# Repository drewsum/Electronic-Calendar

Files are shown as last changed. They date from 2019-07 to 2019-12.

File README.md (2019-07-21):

# Electronic-Calendar
Small PCB to show Time, Date, and Day of the Week. Centered around a PIC32MZ

Hardware:
KiCad Project for single PCB is located in hdw/KiCad_Project
Built in KiCad 5.1.0
Requires drewsum's custom libraries for KiCad schematic symbols and PCB footprints, located at: https://github.com/drewsum/KiCad_Custom_Libraries.git

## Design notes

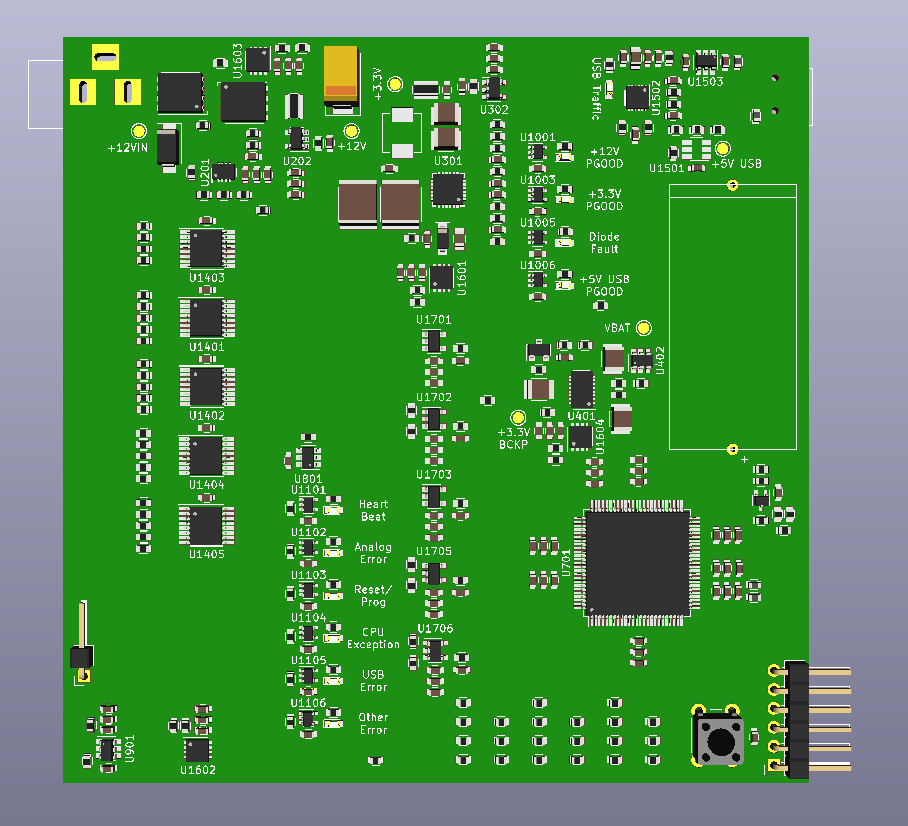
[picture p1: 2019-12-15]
hdw/KiCad_Project/Electronic_Calendar/render_front.PNG

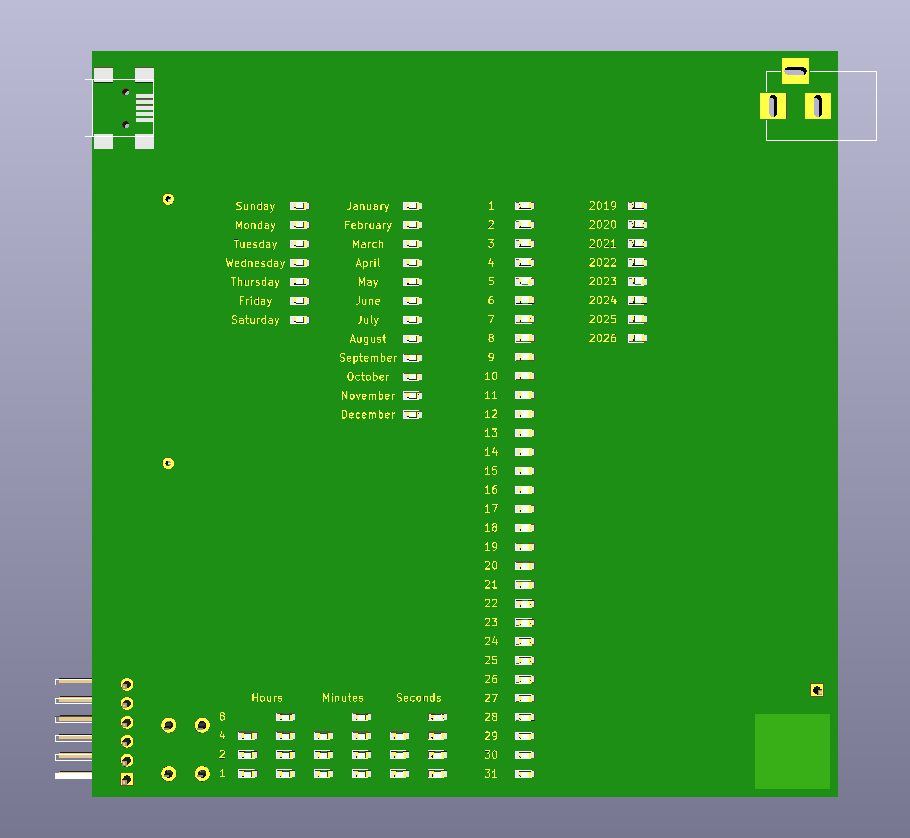
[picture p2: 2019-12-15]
hdw/KiCad_Project/Electronic_Calendar/render_back.PNG

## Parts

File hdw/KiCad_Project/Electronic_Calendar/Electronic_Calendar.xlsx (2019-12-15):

Qty | Reference(s) | Value | Digi-Key PN
1 | BT401 | BR-2/3AE5SPN | P226-ND
51 | C201, C204, C205, C305, C307, C311, C316, C401, C601, C602, C801, C802, C807, C808, C813, C814, C819, C820, C825, C902, C1001, C1003, C1005, C1006, C1101, C1102, C1103, C1104, C1105, C1106, C1401, C1402, C1403, C1404, C1405, C1501, C1502, C1503, C1504, C1506, C1507, C1510, C1601, C1602, C1603, C1610, C1701, C1702, C1709, C1717, C1718 | 0.1uF | 311-1344-1-ND
28 | C202, C206, C304, C313, C803, C804, C809, C810, C815, C816, C821, C822, C901, C903, C1604, C1605, C1606, C1611, C1703, C1704, C1707, C1708, C1711, C1715, C1719, C1720, C1723, C1724 | 10nF | 1276-1921-1-ND
23 | C203, C207, C208, C314, C317, C805, C806, C811, C812, C817, C818, C823, C824, C904, C1607, C1608, C1609, C1612, C1705, C1706, C1713, C1721, C1722 | 1nF | 1276-1018-1-ND
1 | C209 | 100uF | 718-1102-1-ND
2 | C301, C302 | 22uF | 445-1453-1-ND
1 | C306 | 62pF | 1276-2320-1-ND
2 | C308, C310 | 15pF | 478-10289-1-ND
1 | C309 | 2.2uF | 445-5691-1-ND
5 | C312, C315, C402, C403, C404 | 47uF | 490-4844-1-ND
1 | C1505 | 4.7uF | 1276-2972-1-ND
2 | C1508, C1509 | 47pF | 478-1171-1-ND
1 | D201 | 24V | SMAJ24CALFCT-ND
3 | D301, D1601, D1602 | MBR0530 | MBR0530T1GOSCT-ND
4 | D1001, D1003, D1006, D1101 | Green | 160-1446-1-ND
85 | D1005, D1102, D1103, D1104, D1105, D1106, D1201, D1202, D1203, D1204, D1205, D1206, D1207, D1208, D1209, D1210, D1211, D1212, D1213, D1214, D1215, D1216, D1217, D1218, D1219, D1220, D1221, D1222, D1223, D1224, D1225, D1226, D1227, D1228, D1229, D1230, D1231, D1232, D1233, D1234, D1235, D1236, D1237, D1238, D1239, D1240, D1241, D1242, D1243, D1244, D1245, D1246, D1247, D1248, D1249, D1250, D1251, D1252, D1253, D1254, D1255, D1256, D1257, D1258, D1301, D1302, D1303, D1304, D1305, D1306, D1307, D1308, D1309, D1310, D1311, D1312, D1313, D1314, D1315, D1316, D1317, D1318, D1319, D1320, D1321 | Red | 160-1447-1-ND
1 | D1501 | Yellow | 160-1448-1-ND
1 | DOC1501 | COM_Port_Settings
1 | DOC1601 | 0x18
1 | DOC1602 | 0x19
1 | DOC1603 | 0x1A
1 | DOC1604 | 0x1B
1 | J201 | +12V IN | CP-202BH-ND
1 | J601 | PICKIT3 | 2057-PH1RA-06-UA-ND
1 | J1501 | USB_B_Mini | 732-2109-1-ND
1 | L301 | 0.47uH | 541-1231-1-ND
4 | L801, L802, L1501, L1502 | 600R 0.5A | 732-2389-1-ND
2 | Q201, Q202 | IPC100N04S51R2ATMA1 | IPC100N04S51R2ATMA1CT-ND
1 | Q401 | 2N7002
1 | Q601 | BSS214NW | BSS214NWH6327XTSA1CT-ND
1 | R201 | 6.04M | 541-6.04MHCT-ND
1 | R202 | 86.6k | 311-86.6KHRCT-ND
4 | R203, R401, R402, R407 | 243k | 311-243KHRCT-ND
4 | R204, R302, R307, R310 | 100k | A106046CT-ND
4 | R205, R206, R304, R601 | 10 | YAG3351CT-ND
55 | R207, R301, R403, R406, R602, R604, R801, R902, R1101, R1102, R1105, R1106, R1109, R1110, R1401, R1402, R1403, R1404, R1405, R1406, R1407, R1408, R1409, R1410, R1411, R1412, R1413, R1414, R1415, R1416, R1417, R1418, R1419, R1420, R1421, R1422, R1423, R1424, R1501, R1505, R1506, R1507, R1607, R1608, R1609, R1610, R1611, R1612, R1615, R1616, R1701, R1702, R1707, R1709, R1710 | 10k | RMCF0603FT10K0CT-ND
1 | R208 | 5.1k | YAG3621CT-ND
2 | R209, R309 | 0.02 | P16010CT-ND
1 | R210 | 249k | RR08P249KDCT-ND
2 | R303, R308 | 22.1k | P22.1KHCT-ND
1 | R305 | 63.4k | 541-63.4KHCT-ND
1 | R306 | 13.3k | P13.3KHCT-ND
8 | R404, R405, R901, R1703, R1704, R1705, R1711, R1712 | 499 | P499HCT-ND
1 | R603 | 100 | A106047CT-ND
1 | R605 | 0 | PN
37 | R606, R1001, R1003, R1005, R1006, R1103, R1104, R1107, R1108, R1111, R1112, R1201, R1202, R1203, R1204, R1301, R1302, R1303, R1304, R1305, R1306, R1307, R1308, R1309, R1310, R1311, R1312, R1313, R1314, R1315, R1316, R1317, R1318, R1319, R1320, R1321, R1510 | 1k | RMCF0603FT1K00CT-ND
1 | R1502 | 487k | 311-487KHRCT-ND
1 | R1503 | 6.04k | RMCF0603FT6K04CT-ND
1 | R1504 | 40.2k | 311-40.2KHRCT-ND
2 | R1508, R1509 | 27 | RMCF0603FT27R0CT-ND
1 | R1708 | 1.2k | MCT0603-1.20K-CFCT-ND
1 | SW601 | MRST | 450-1650-ND
1 | SW901 | Cap_Touch
1 | U201 | LTC4365DDB | LTC4365IDDB#TRMPBFCT-ND
2 | U202, U302 | INA138 | INA138NACT-ND
1 | U301 | LTC3605A_UF | LTC3605AIUF#TRPBFCT-ND
1 | U401 | LTC4415DHC | LTC4415EDHC#PBF-ND
2 | U402, U801 | TPS22929D | 296-38579-1-ND
1 | U701 | PIC32MZ2048EFG100_IPT | PIC32MZ2048EFG100-I/PT-ND
1 | U901 | AT42QT1010-TSHR | AT42QT1010-TSHRCT-ND
9 | U1001, U1003, U1006, U1101, U1102, U1103, U1104, U1105, U1106 | 74LVC1G06 | 296-8484-1-ND
1 | U1005 | 74LVC1G17 | 296-11934-1-ND
5 | U1401, U1402, U1403, U1404, U1405 | 74HC138 | 296-8228-1-ND
1 | U1501 | LT6700-1-S6 | LT6700CS6-1#TRMPBFCT-ND
1 | U1502 | FT234XD | 768-1178-1-ND
1 | U1503 | TPD3S014DBVR | 296-38835-1-ND
4 | U1601, U1602, U1603, U1604 | MCP9804_DFN | MCP9804T-E/MCCT-ND
5 | U1701, U1702, U1703, U1705, U1706 | OPA340NA | 296-26275-1-ND

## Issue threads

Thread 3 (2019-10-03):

+3.3V Power Supply Stability

drewsum, 2019-10-03:
Compensation is wrong on POS3P3_Power_Supply. Try RITH = 30.1k, CITH = 330pF, CITHP = 22pF, maybe double up on output capacitance. Try to get the switch node to not look like garbage. Also consider lowering switching frequency to 1 MHz from 2.5 MHz

drewsum, 2019-10-04:
Changed Cff to 33pF, no effect

drewsum, 2019-10-04:
Changed Rith to 33k, no effect

drewsum, 2019-10-04:
Changed Cith to 220pF, seems to be less unstable, still not great

drewsum, 2019-10-04:
Changed Cithp to 47pF, no effect

drewsum, 2019-10-04:
Added 200uF ceramic output capacitance, that really seemed to help

drewsum, 2019-10-04:
Added 44uF ceramic capacitance around the board, seemed to help a little more

drewsum, 2019-10-04:
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

Closed 2019-10-25.

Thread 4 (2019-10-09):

Add error handling for USB UART DMA buffer overruns

drewsum, 2019-10-09:
Add more error handling flags for this

drewsum, 2019-11-02:
Flags added, need to write code to implement them

Closed 2019-11-02.

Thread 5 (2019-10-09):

PIC32MZ EF notes for future projects

drewsum, 2019-10-09:
- The RTCC should be configured to use SOSC oscillator instead of INTOSC since INTOSC does not run in sleep mode
- PGC2/PGD2 should be used for programming from PIC KIT 3 since only these programming pins support debugging, not PGC1/PGD1

drewsum, 2019-10-22:
USB UART should have WAKE IN SLEEP disabled/not set on UART initialization since this is what causes the first two lines from PuTTY transmit to be ignored

drewsum, 2019-10-24:
For VDD >= 2.5V, analog input charge pump should be disabled.
Do the following on ADC init function:
`ADCCON1bits.AICPMPEN = 0;
CFGCONbits.IOANCPEN = 0;`

drewsum, 2019-11-11:
SOSC must be fed from an external oscillator, not crystal

drewsum, 2019-11-13:
In the future, I should add a hardware deglitch filter on the capacitive touch signals, since the signal appears to be bouncy

drewsum, 2019-11-14:
Refactor 32MZ interrupt stuff with Macros

drewsum, 2019-11-14:
Only use external oscillators with these MCUs for SOSC and POSC, no crystals allowed per errata

drewsum, 2019-11-16:
Also, don't connect any input signals to any pins that double as JTAG TDO as this pin apparently flutters high and low during ICSP programming. Only use this pin as an output

drewsum, 2019-11-16:
Avoid using the USBID pin (RF3), I believe there's some weird behavior with this pin when USB is disabled. Seeing weird GPIO states with USB disabled

drewsum, 2019-11-16:
> Avoid using the USBID pin (RF3), I believe there's some weird behavior with this pin when USB is disabled. Seeing weird GPIO states with USB disabled

This was confirmed to be an issue on PIC forums and in the datasheet. If VUSB is left unpowered (connected to VSS like I always do) RF3 is not available as a GPIO. Don't use RF3 in the future. This is why the MON_LED stays lit even when disabled

drewsum, 2019-11-19:
Add some kind of bulk decoupling cap to the MCU besides the smaller value decoupling

drewsum, 2019-11-19:
When designing circuits that use the RTCC, don't design an MCU VDD backup circuit like earlier projects.  Use a dedicated RTC IC with backup battery. The MZ is too high power even in sleep, and I ran into a lot of issues getting IDLE mode to work with a backup battery. This sucks but it's not worth the time to get everything working with a backup battery only for the time to be incorrect on wake from sleep and the battery life to be a day long.

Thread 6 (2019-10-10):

Try to convert USB UART receive parser into object based implementation

drewsum, 2019-10-10:
insteadof using an asston of if statements for each serial command, trying switching to using objects with methods and command strings stored within them, and looping through them. That would be awesome

drewsum, 2019-10-22:
Ended up doing this with a hash table, with UTHash.h

Closed 2019-10-22.

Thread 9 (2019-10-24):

Disable Analog Input Charge Pump

drewsum, 2019-10-24:
Pretty sure the analog input charge pump is causing strange ADC conversion results. This bit is enabled by default, and should be disabled in init function

drewsum, 2019-10-24:
For VDD >= 2.5V, analog input charge pump should be disabled.
Do the following on ADC init function:
`ADCCON1bits.AICPMPEN = 0;`
`CFGCONbits.IOANCPEN = 0;`

Closed 2019-10-25.

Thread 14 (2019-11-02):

Add CPU Exceptions error handler flag

drewsum, 2019-11-02:
So that CPU exceptions can be logged across device resets

Closed 2019-11-02.

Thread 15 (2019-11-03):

Fix WDT and DMT timeouts with addition of I2C

drewsum, 2019-11-03:
I've seen some WDT and DMT timeouts after adding the I2C functionality for digital temp sensors. This is probably because of I2C code blocking stuff, and the CPU core getting tied up in the while loops that are built into the I2C code.

* Consider making I2C non-blocking (this would be really hard)
* Also consider clearing the WDT and DMT during I2C blocking while loops

drewsum, 2019-11-05:
This could have something to do with the clear watchdog timer and deadman timer stuff not being all a single instruction operation... I'm calling a function rather than doing inline stuff. Or something to do with system unlock. Think about it

drewsum, 2019-11-06:
It also would appear that the reason this is happening is that sometimes the PIC core randomly stalls. I've seen it where the WDT/DMT may or may not save it/reset it. This should definitely be figured out. May or may not be related to I2C

drewsum, 2019-11-11:
Not related to I2C, it happens on older git commits from long before I2C being integrated. Weird CPU exception issue I think with TLB reads

drewsum, 2019-11-12:
It would appear that this problem was related to common scan ADC cores being assigned differing sampling times/input clock dividers. With all common scan ADCs (except ADC7) set to have the same SAMC and ADCDIV, this problem appears to have disappeared

drewsum, 2019-11-16:
This was both related to the ADC issue described above, and another issue with the heartbeat timer ISR bring called in a loop. Clearing timer 1 every call of the ISR appears to have fixed this

Closed 2019-11-16.

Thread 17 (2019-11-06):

Refactor 32MZ interrupt stuff with Macros

drewsum, 2019-11-06:
Replace the old school switch/case statements with setting bits with macros. This will suck so maybe find a way to script it

drewsum, 2019-11-14:
Not doing this for this project

Closed 2019-11-14.

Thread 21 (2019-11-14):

Figure out MON_LED staying on when device is in reset/idle mode

drewsum, 2019-11-14:
Weird leakage current going on

Closed 2019-11-16.

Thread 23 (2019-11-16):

Add clock switching/slew to pushbutton ISRs for later use in PGOOD failure ISRs

drewsum, 2019-11-16:

drewsum, 2019-11-18:
Did this but without clock slew since it's unclear how to use the SLEWCON register and how it interacts with OSCCON

Closed 2019-11-18.

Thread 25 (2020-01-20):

Figure out random stalls

drewsum, 2020-01-20:
Occasionaly the CPU does not return to main. I'm guessing that an IRQ is not being properly cleared or something. The heartbeat appears to keep beating since there is no WDT timeout when this happens.

drewsum, 2020-01-20:
This may have something to do with the `MCP9804_temp_results` structure not being volatile. I could see the I2C acquisition stuff trying to write while it's being read.

drewsum, 2020-02-23:
> ~~This may have something to do with the `MCP9804_temp_results` structure not being volatile. I could see the I2C acquisition stuff trying to write while it's being read.~~

This is not the case. I'm pretty sure this has something to do with an ADC interrupt not being cleared properly. There are two different sets of ADC interrupt enables, one within the global interrupt controller and another within the ADC module itself. The documentation on how these interact is unclear because mirochip. I'm experimenting with clearing ADC fault interrupt flags. This issue seemed to disappear when I disabled the ADC and reappeared when the ADC was enabled across builds.

drewsum, 2020-02-26:
Unfortunately my bug fix for clearing ADC fault interrupts didn't work, this is still an issue

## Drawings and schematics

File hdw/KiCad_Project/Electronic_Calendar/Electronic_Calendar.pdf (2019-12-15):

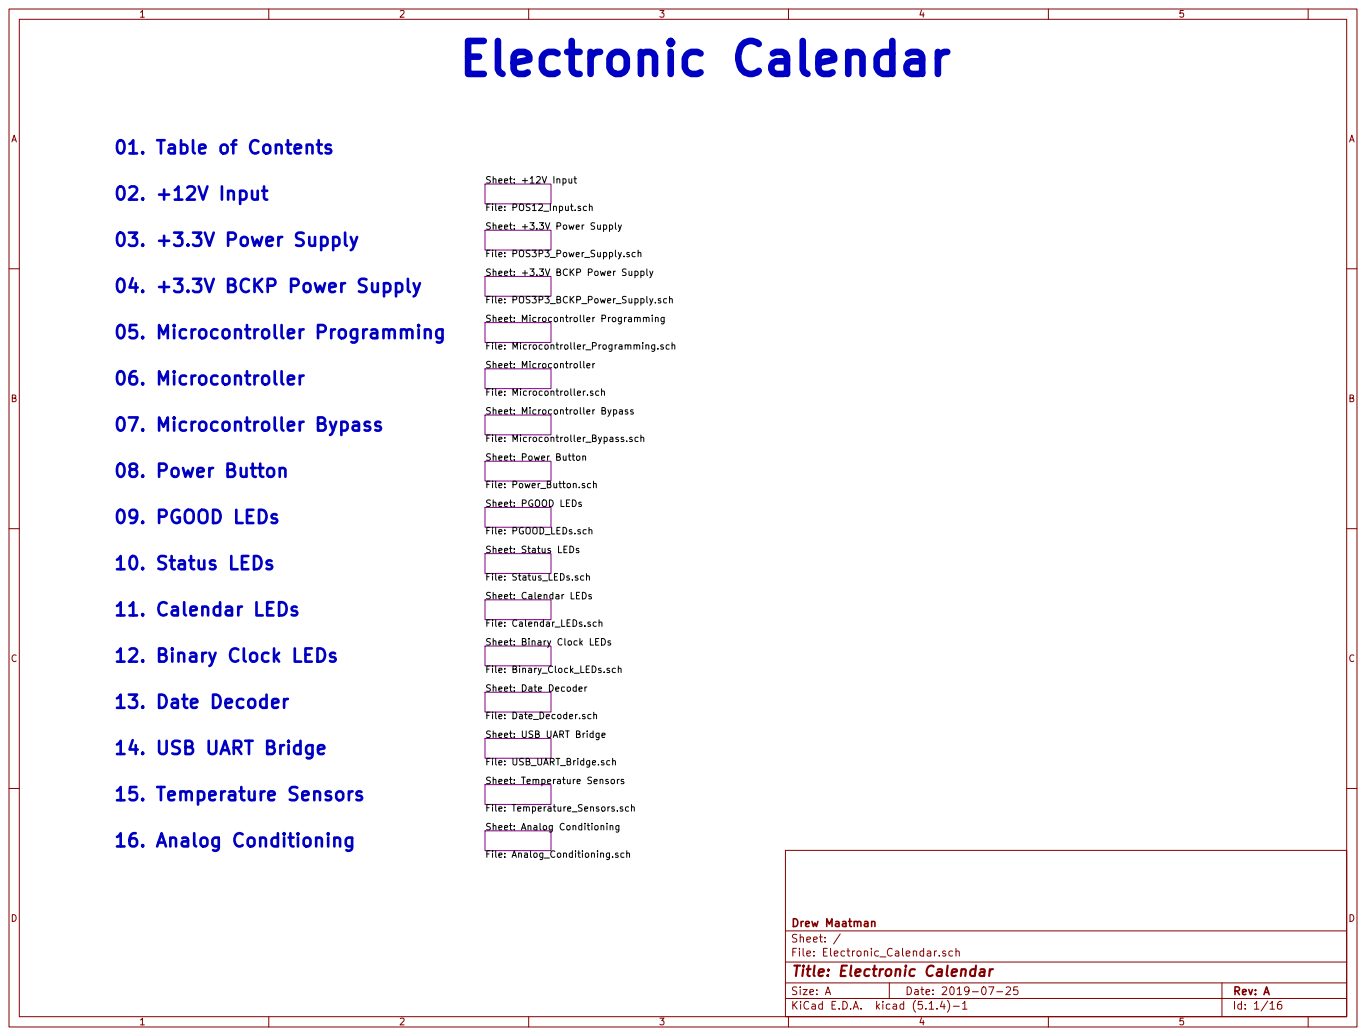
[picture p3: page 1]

Sheet: +12V Input
File: Binary_Clock_LEDs.sch Sheet: Calendar LEDs File: Calendar_LEDs.sch Sheet: Status LEDs File: Status_LEDs.sch Sheet: PGOOD LEDs File: PGOOD_LEDs.sch Sheet: Power Button File: Power_Button.sch Sheet: Microcontroller Bypass

File: POS3P3_Power_Supply.sch
Sheet: +3.3V BCKP Power Supply

File: POS3P3_BCKP_Power_Supply.sch
File: Microcontroller_Bypass.sch Sheet: Microcontroller File: Microcontroller.sch Sheet: Microcontroller Programming

File: USB_UART_Bridge.sch Sheet: Date Decoder File: Date_Decoder.sch Sheet: Binary Clock LEDs

Sheet: USB UART Bridge

File: Electronic_Calendar.sch Sheet: / Drew Maatman

Id: 1/16 Title: Electronic Calendar

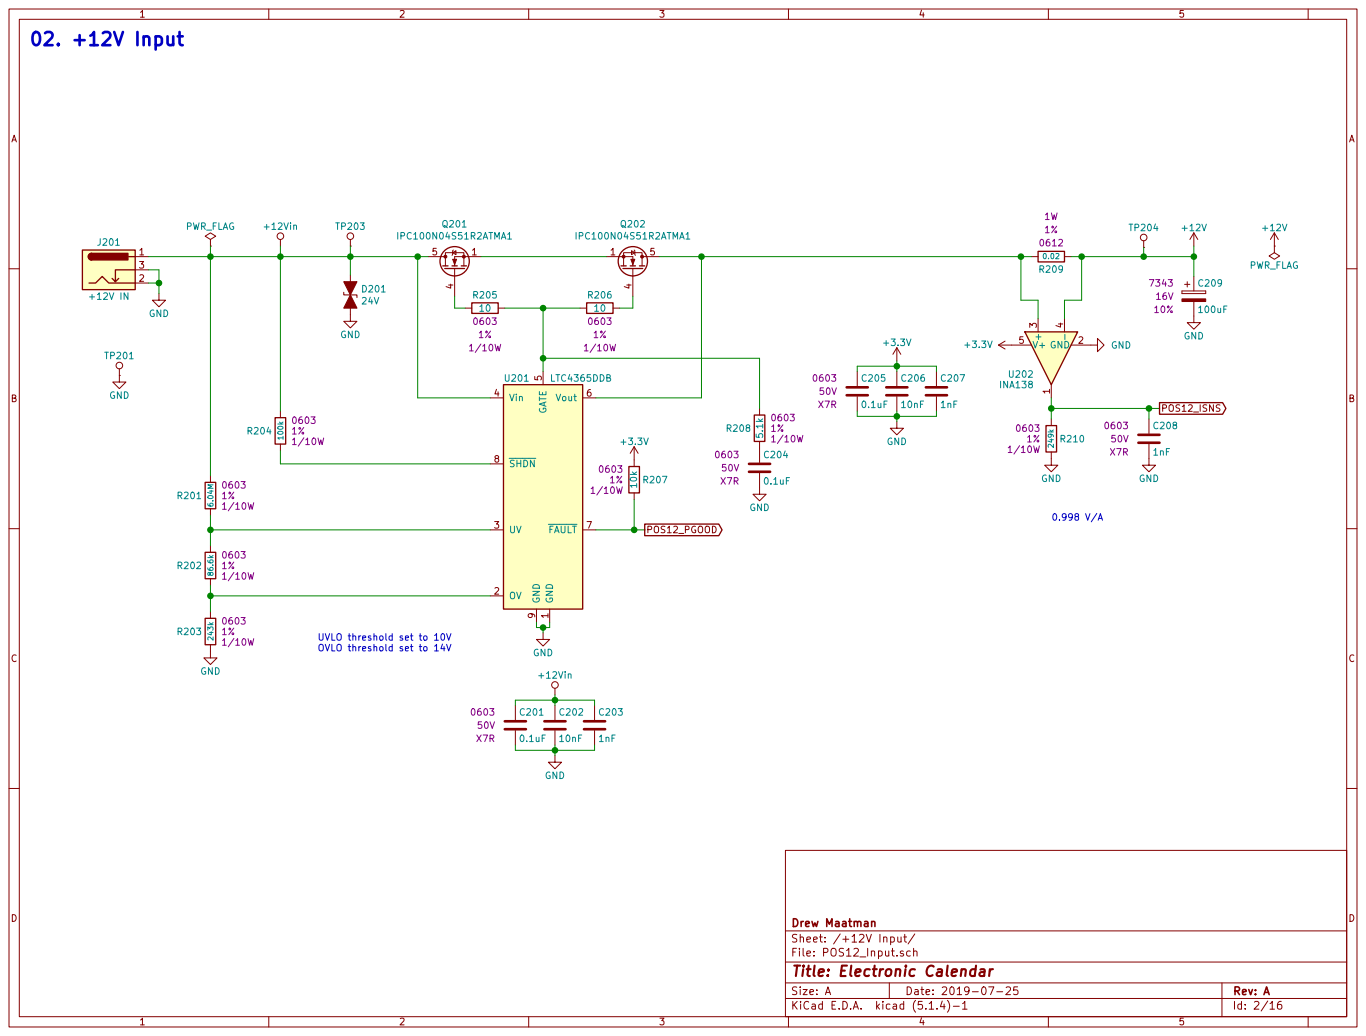
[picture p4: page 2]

POS12_ISNS UVLO threshold set to 10V OVLO threshold set to 14V 02. +12V Input

5 Vout 6 FAULT 7 SHDN 8 GND

1 OV 2 UV 3 Vin 4 GATE

File: POS12_Input.sch
Id: 2/16 Title: Electronic Calendar

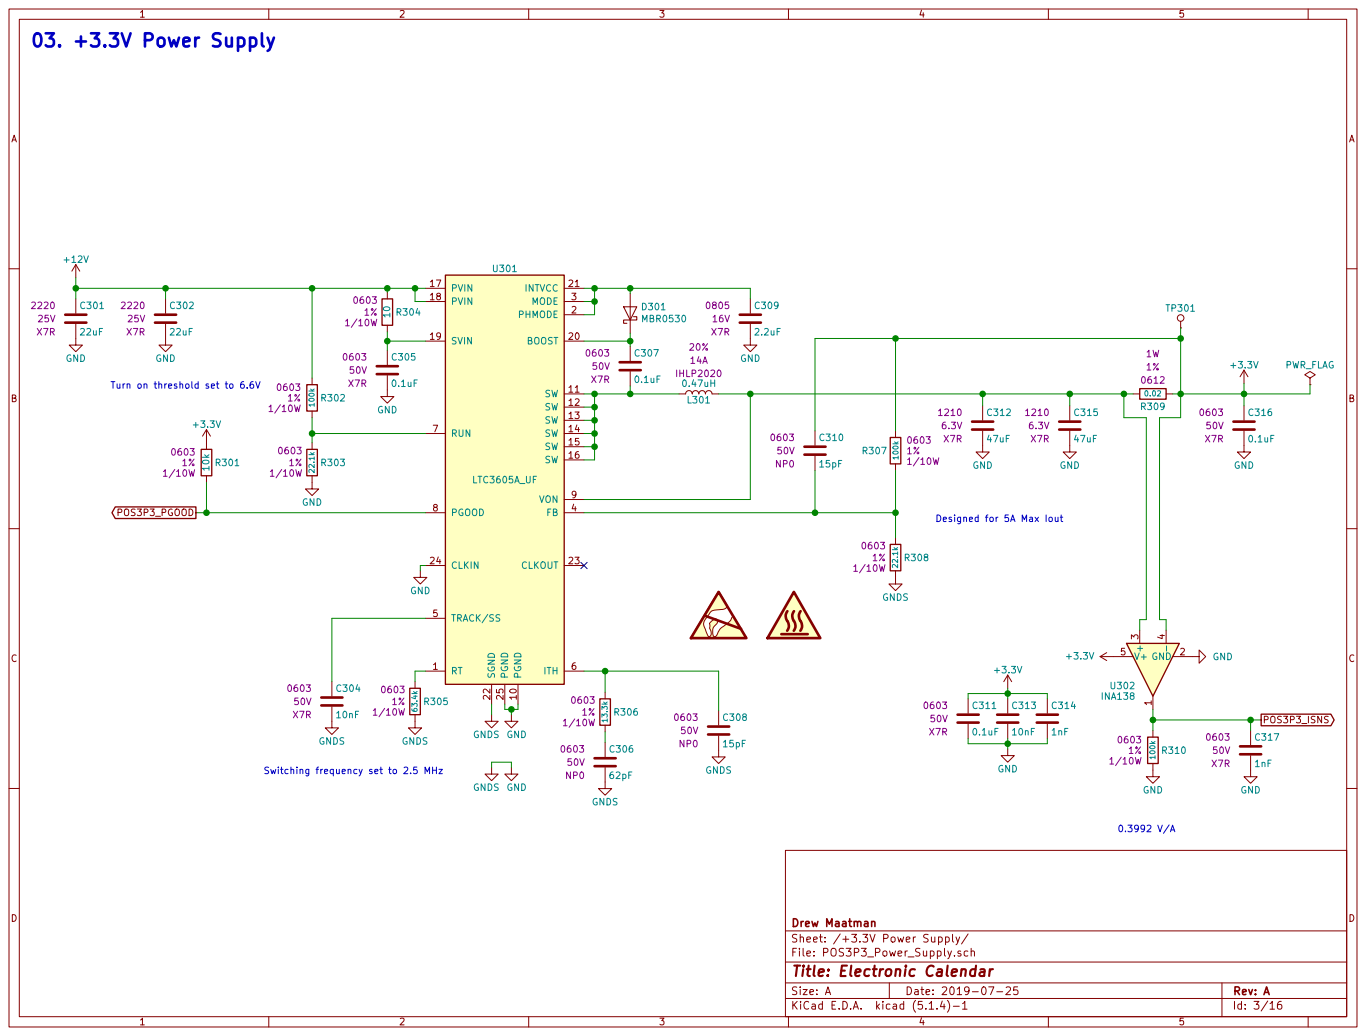
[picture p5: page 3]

Turn on threshold set to 6.6V

Designed for 5A Max Iout

Switching frequency set to 2.5 MHz

File: POS3P3_Power_Supply.sch
Id: 3/16 Title: Electronic Calendar

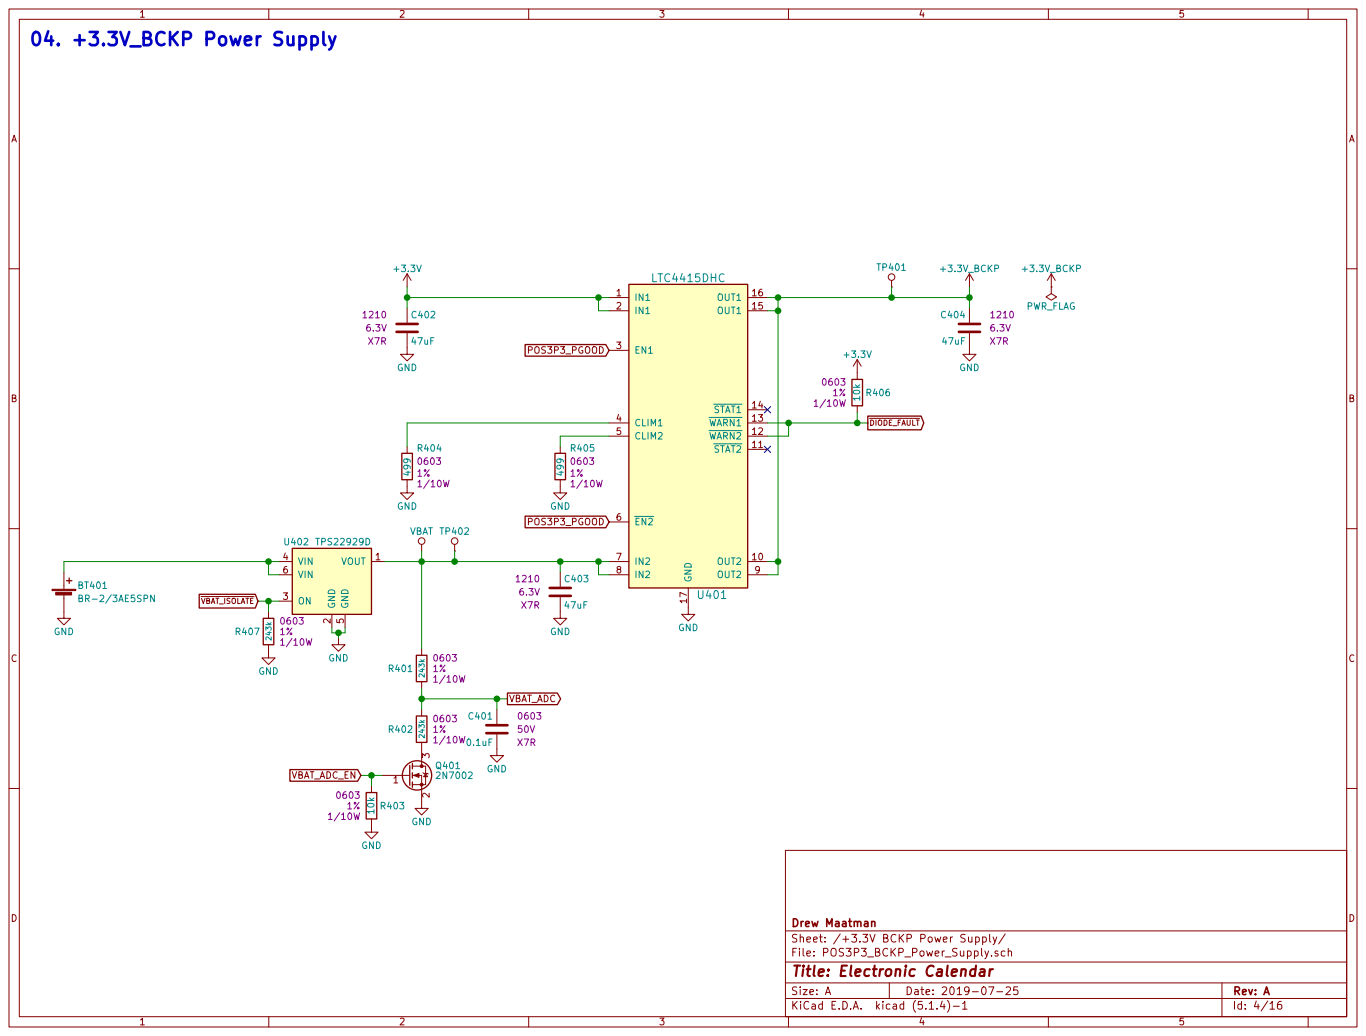
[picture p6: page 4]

Sheet: /+3.3V BCKP Power Supply/ Drew Maatman

File: POS3P3_BCKP_Power_Supply.sch
Id: 4/16 Title: Electronic Calendar

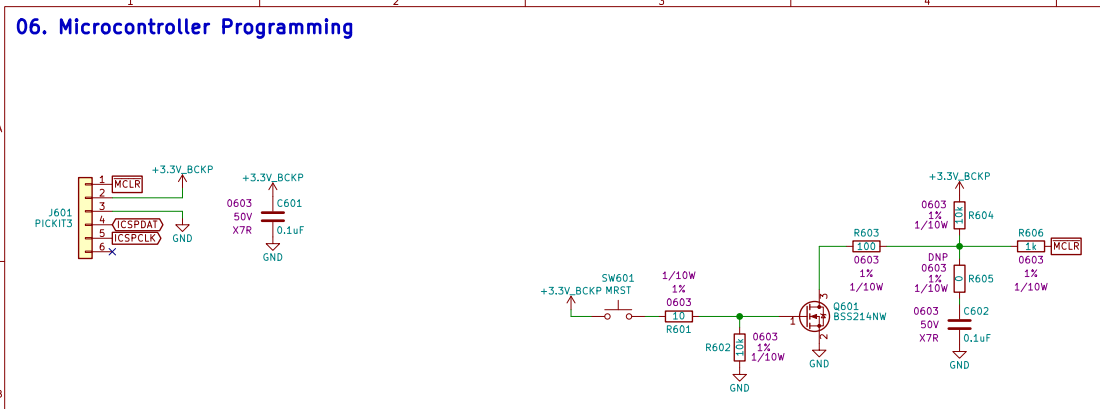
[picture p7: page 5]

ICSPDAT MCLR 06. Microcontroller Programming

Sheet: /Microcontroller Programming/ Drew Maatman

File: Microcontroller_Programming.sch
Id: 5/16 Title: Electronic Calendar

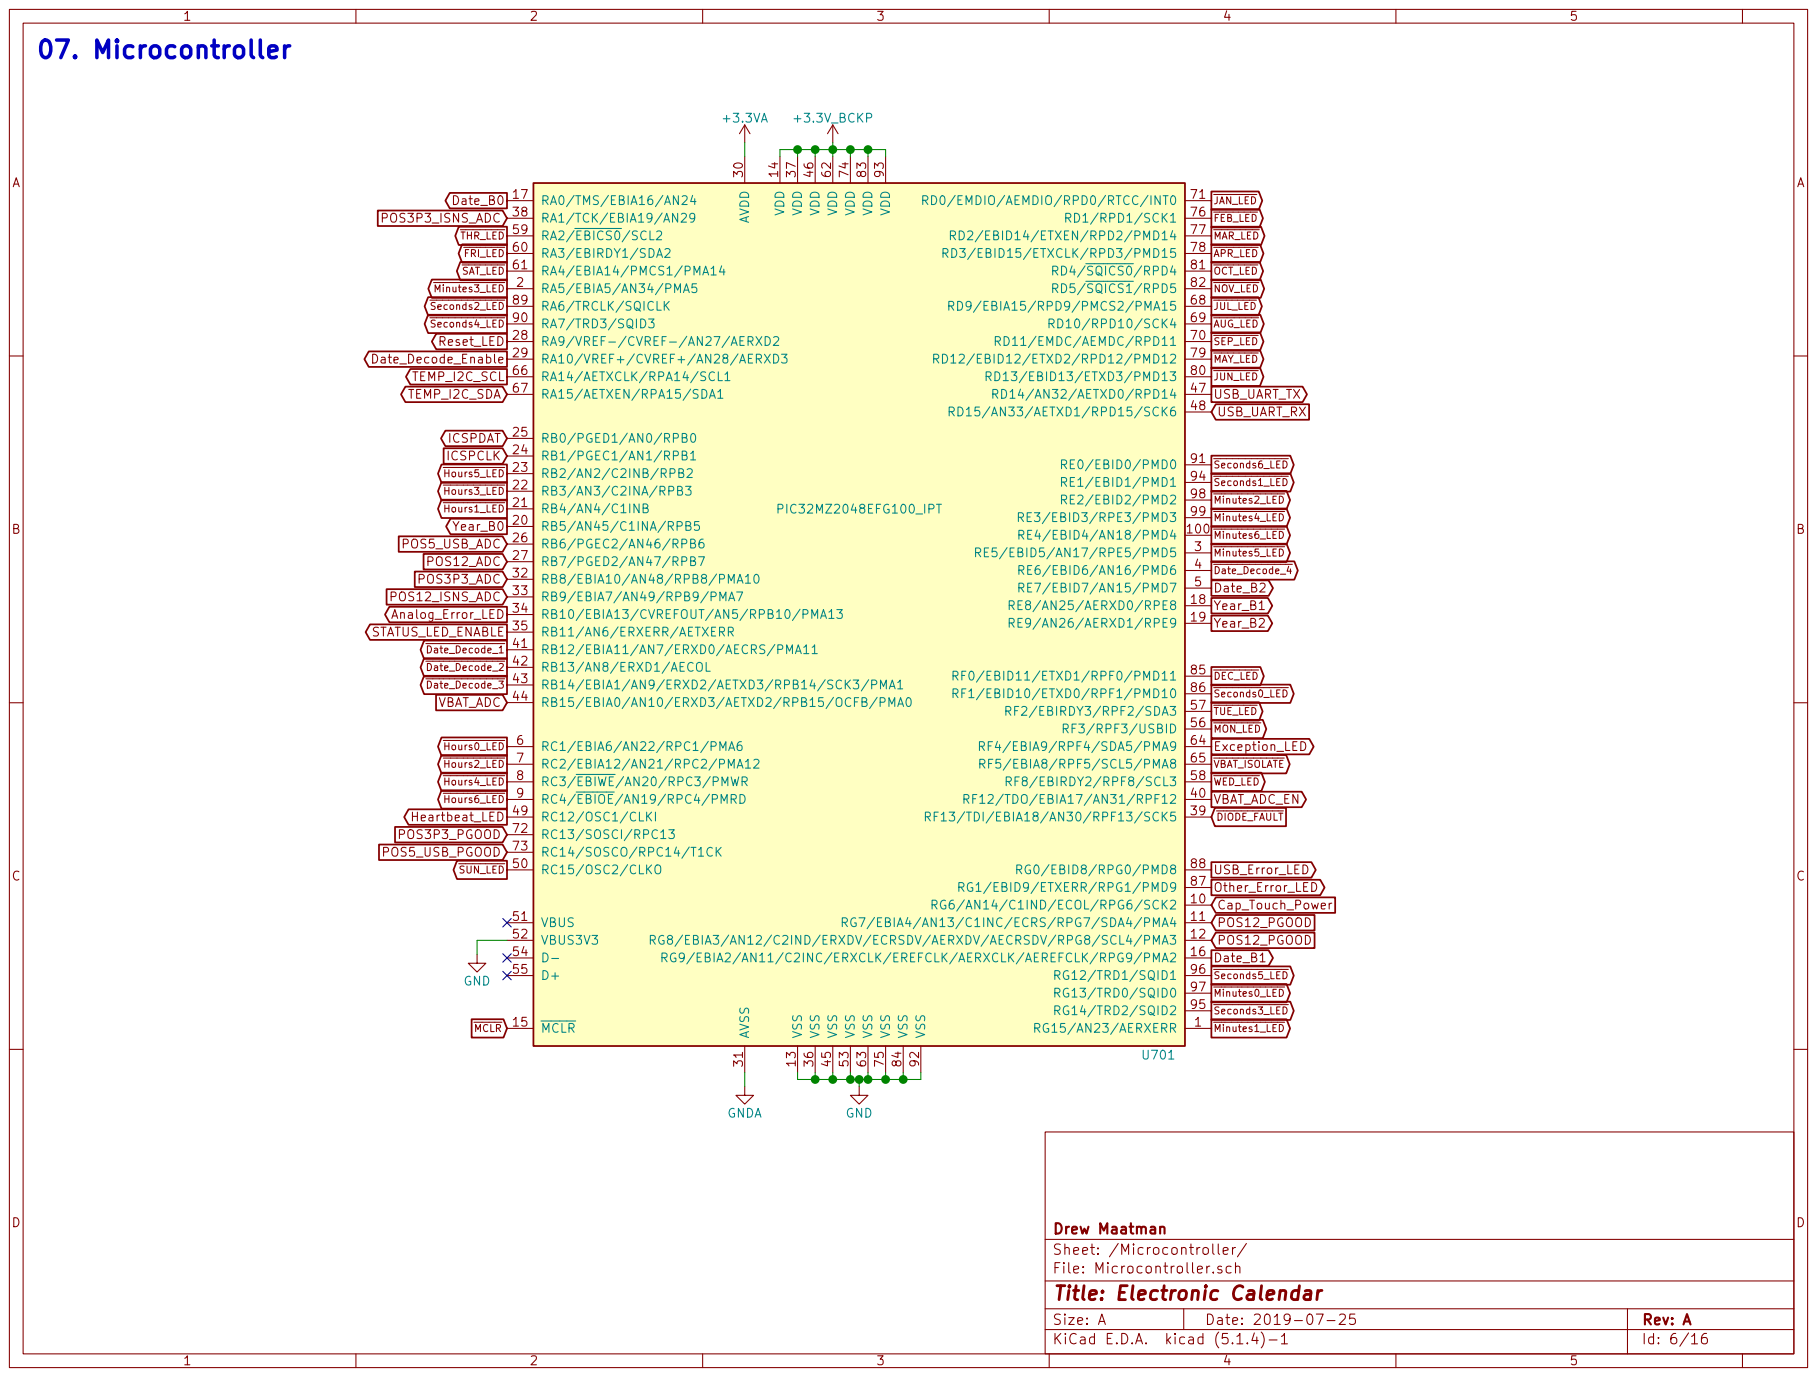
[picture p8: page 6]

Id: 6/16 Title: Electronic Calendar File: Microcontroller.sch Sheet: /Microcontroller/ Drew Maatman

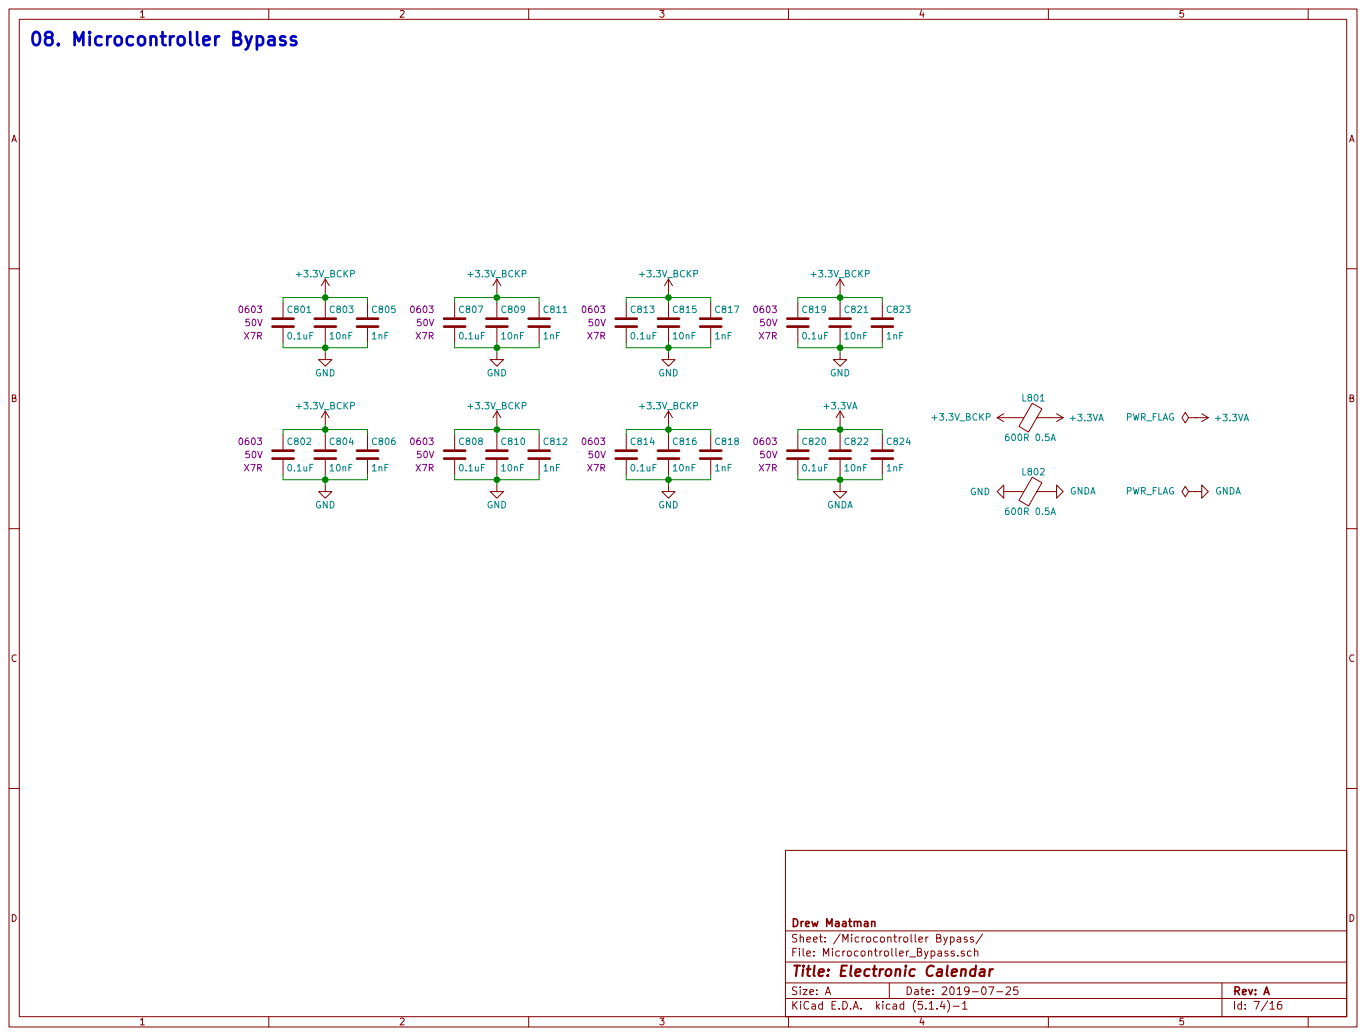
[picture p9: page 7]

Sheet: /Microcontroller Bypass/ Drew Maatman

File: Microcontroller_Bypass.sch
Id: 7/16 Title: Electronic Calendar

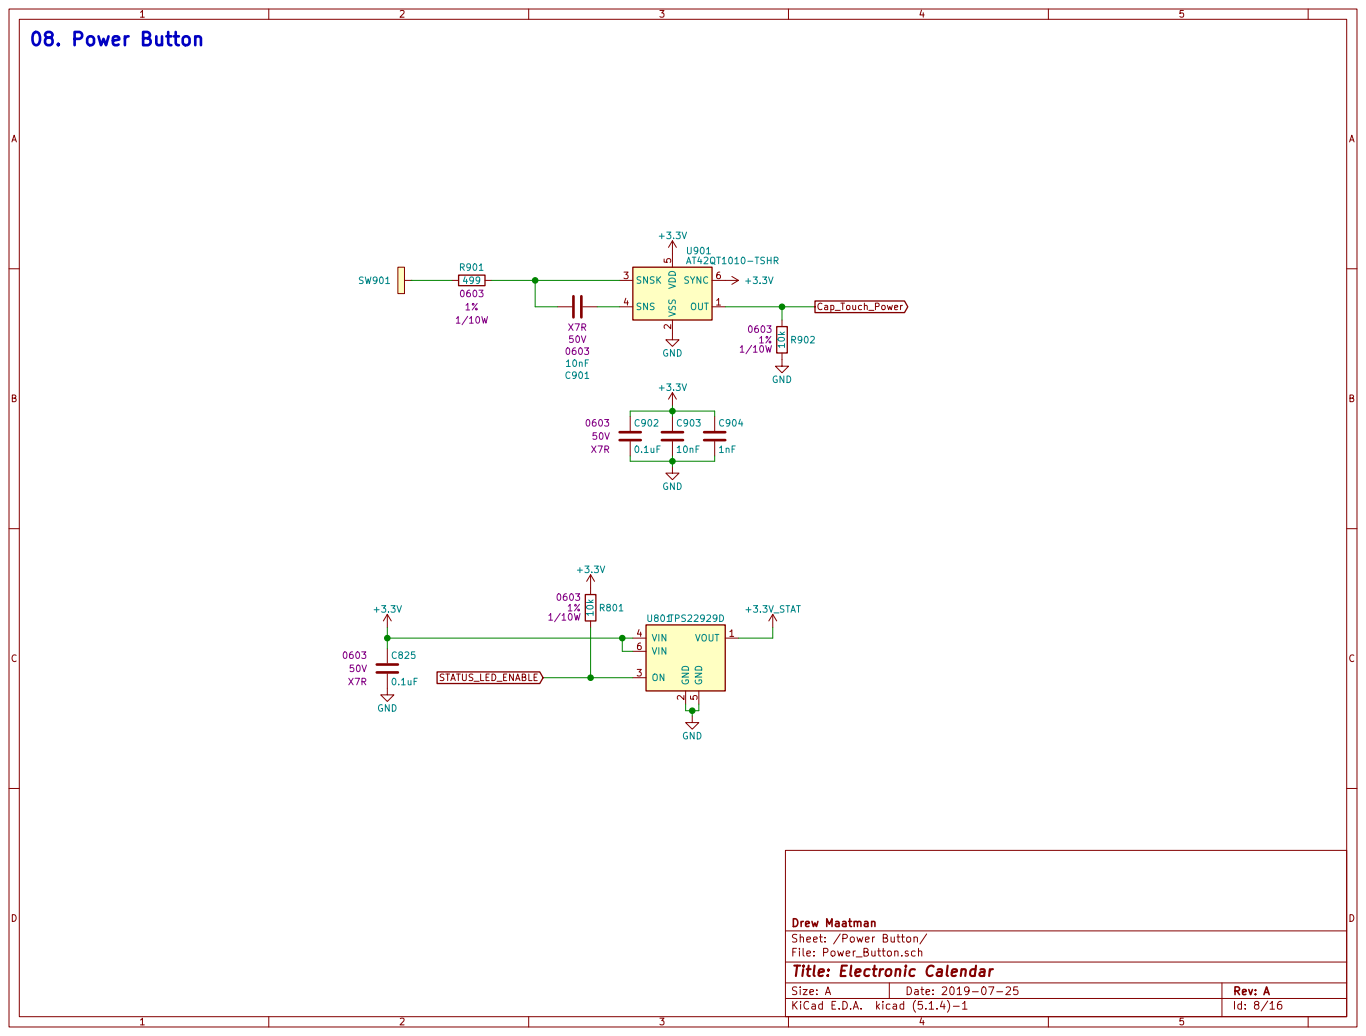
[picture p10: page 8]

File: Power_Button.sch Sheet: /Power Button/ Drew Maatman

Id: 8/16 Title: Electronic Calendar

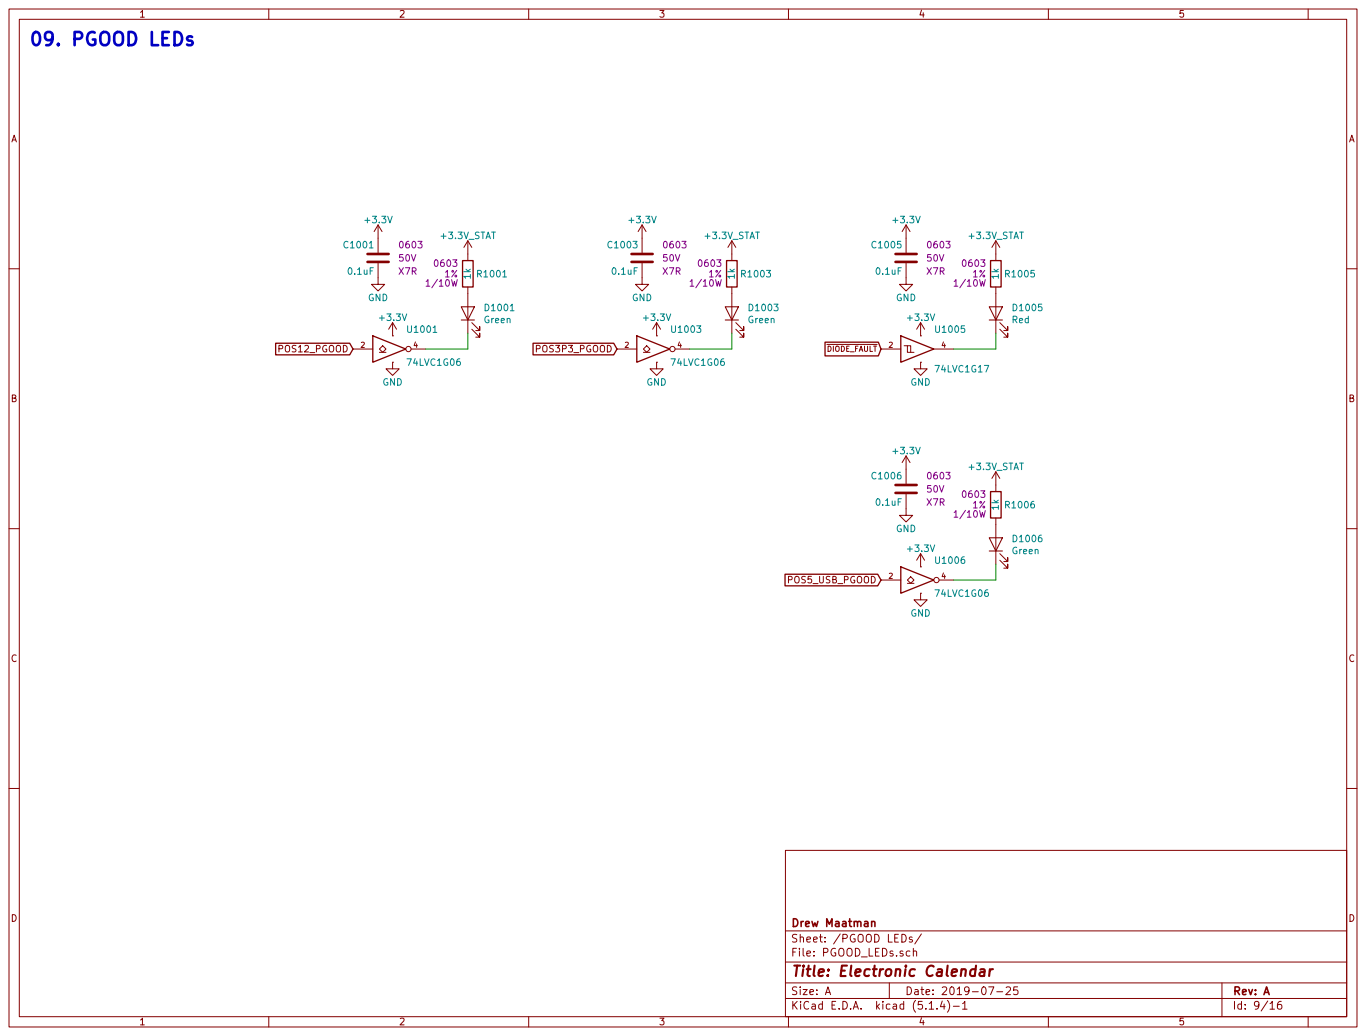
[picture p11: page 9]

File: PGOOD_LEDs.sch Sheet: /PGOOD LEDs/ Drew Maatman

Id: 9/16 Title: Electronic Calendar

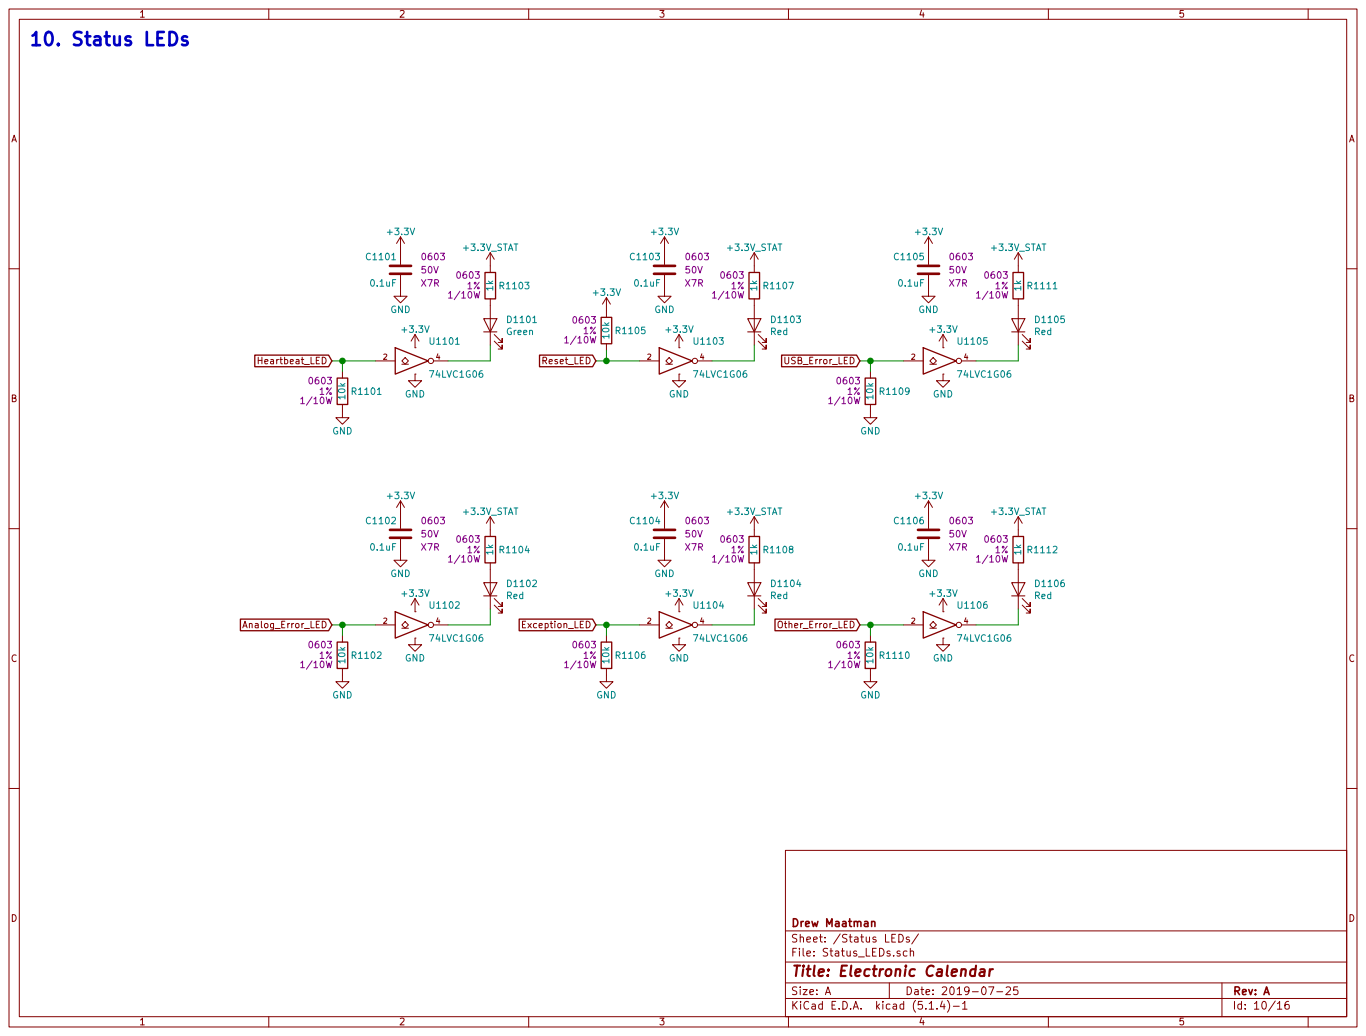
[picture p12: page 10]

File: Status_LEDs.sch Sheet: /Status LEDs/ Drew Maatman

Id: 10/16 Title: Electronic Calendar

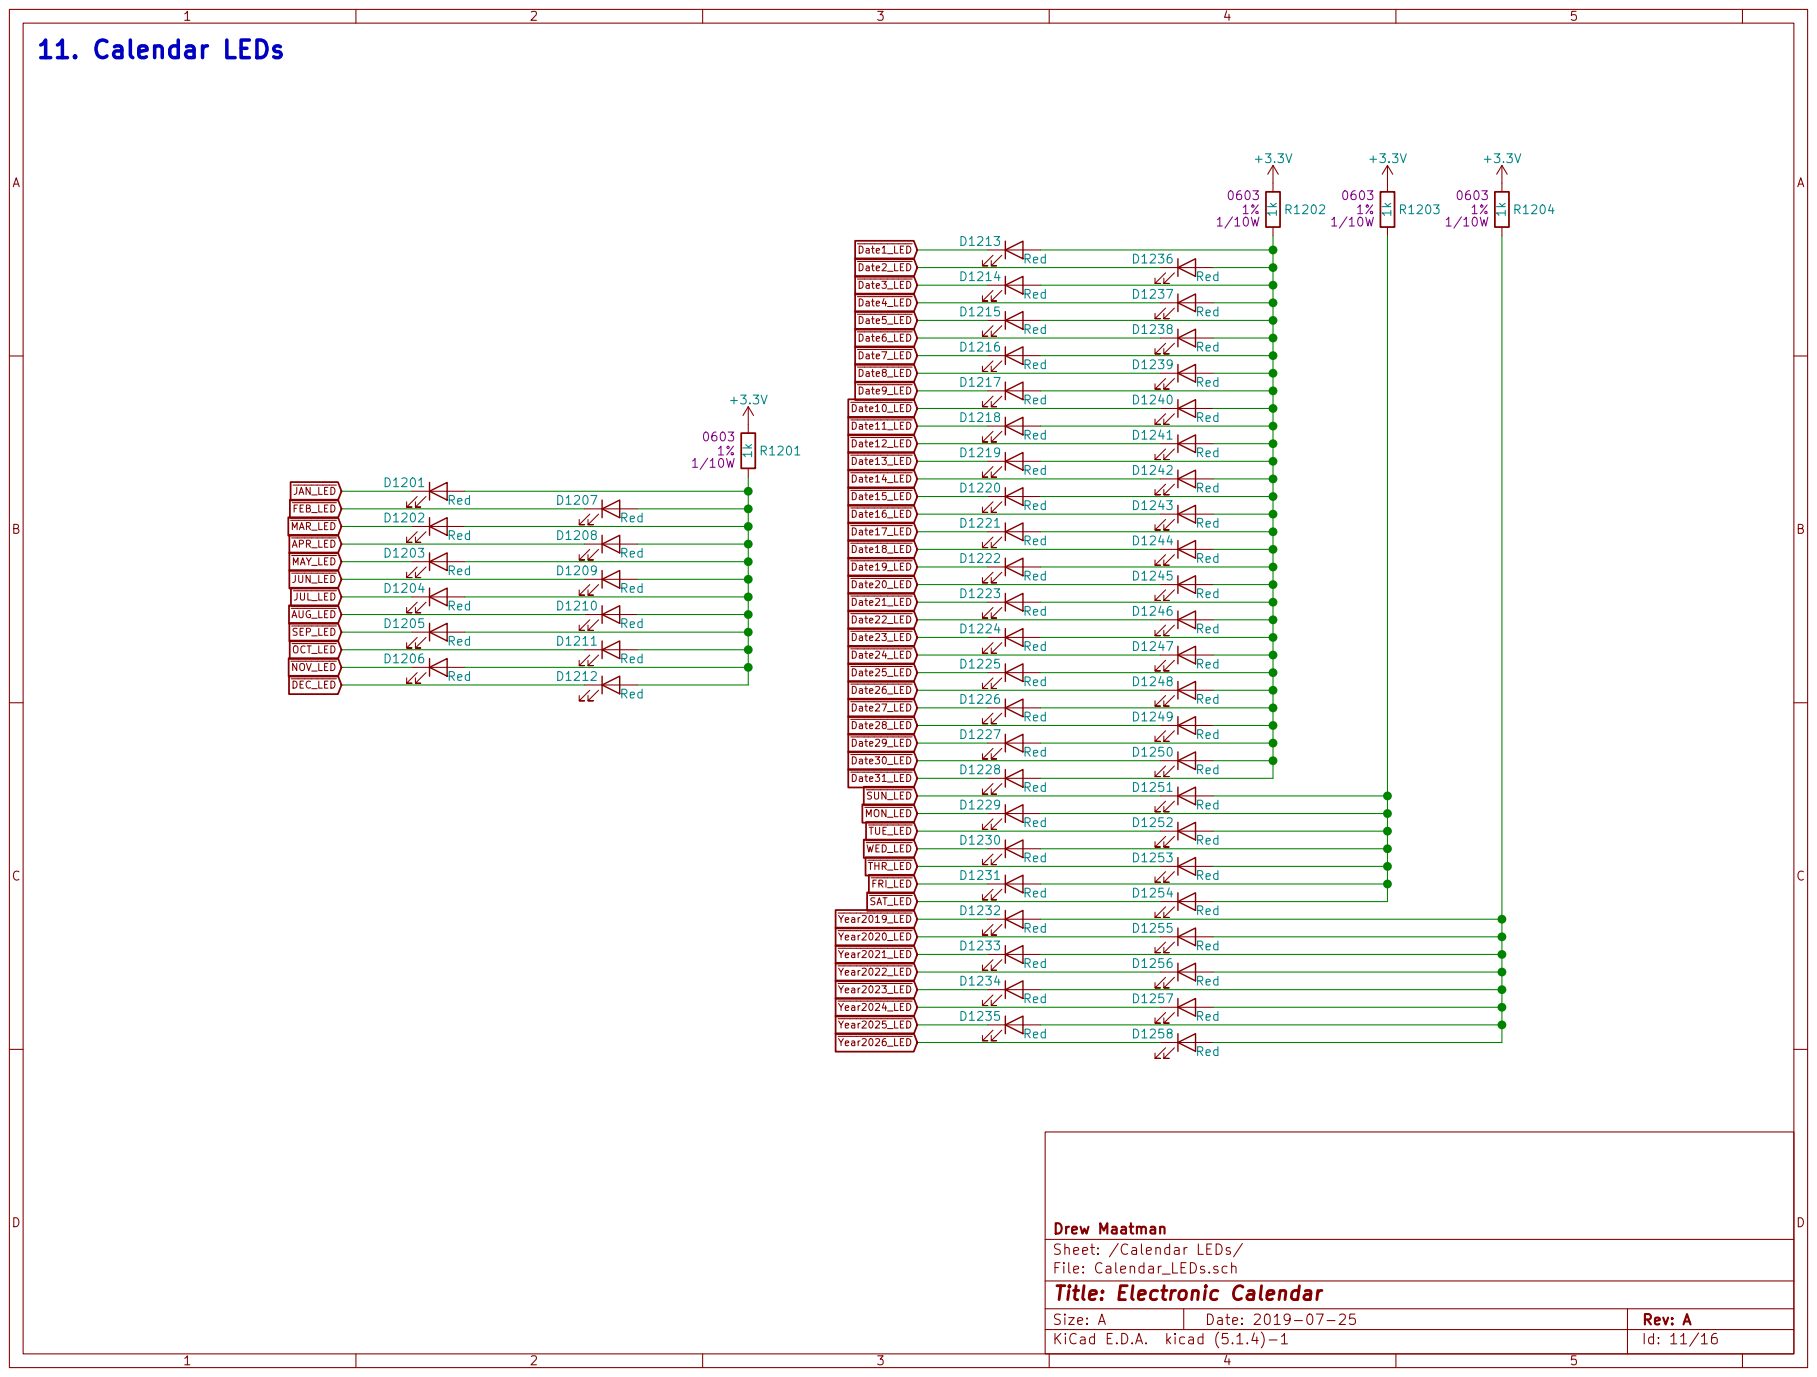
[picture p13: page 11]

Id: 11/16 Title: Electronic Calendar

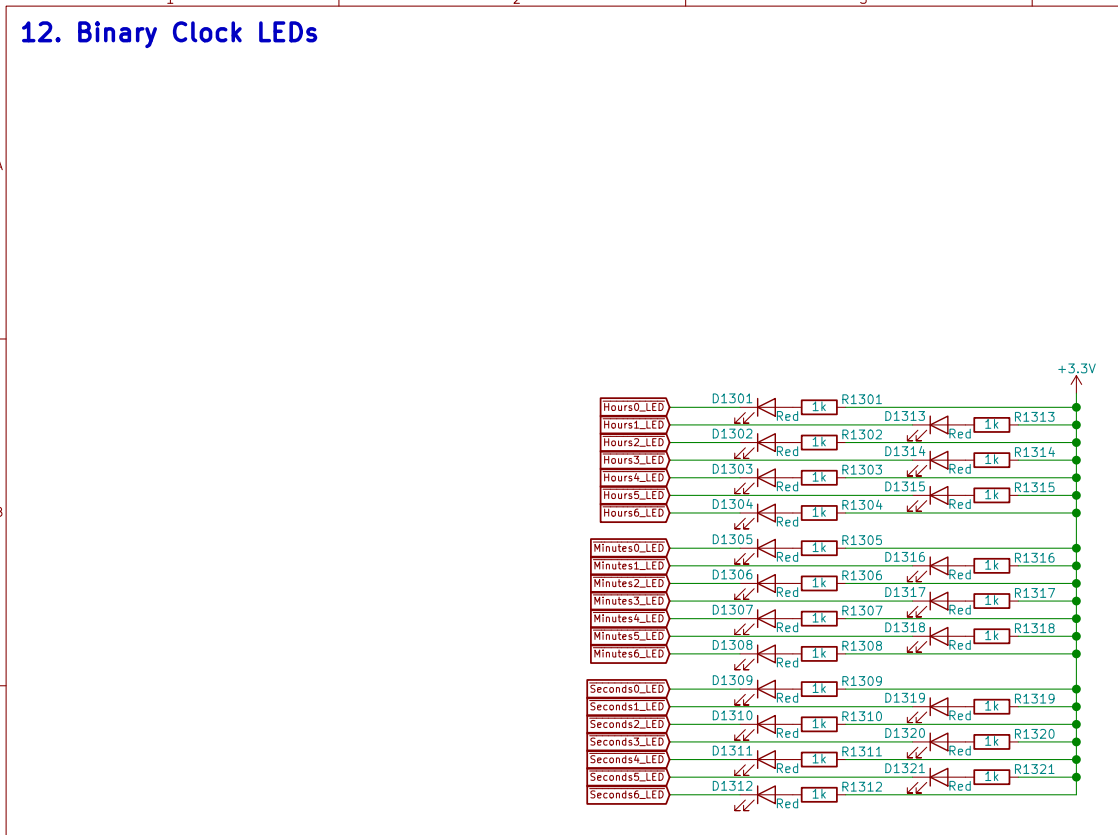
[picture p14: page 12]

File: Binary_Clock_LEDs.sch
Id: 12/16 Title: Electronic Calendar


Id: 13/16 Title: Electronic Calendar


USB Virtual COM Port Settings:

File: USB_UART_Bridge.sch
Id: 14/16 Title: Electronic Calendar


Place near +3.3V Buck Converter Place away from heat dissipating components

Sheet: /Temperature Sensors/ Drew Maatman

File: Temperature_Sensors.sch
Id: 15/16 Title: Electronic Calendar


File: Analog_Conditioning.sch
Id: 16/16 Title: Electronic Calendar

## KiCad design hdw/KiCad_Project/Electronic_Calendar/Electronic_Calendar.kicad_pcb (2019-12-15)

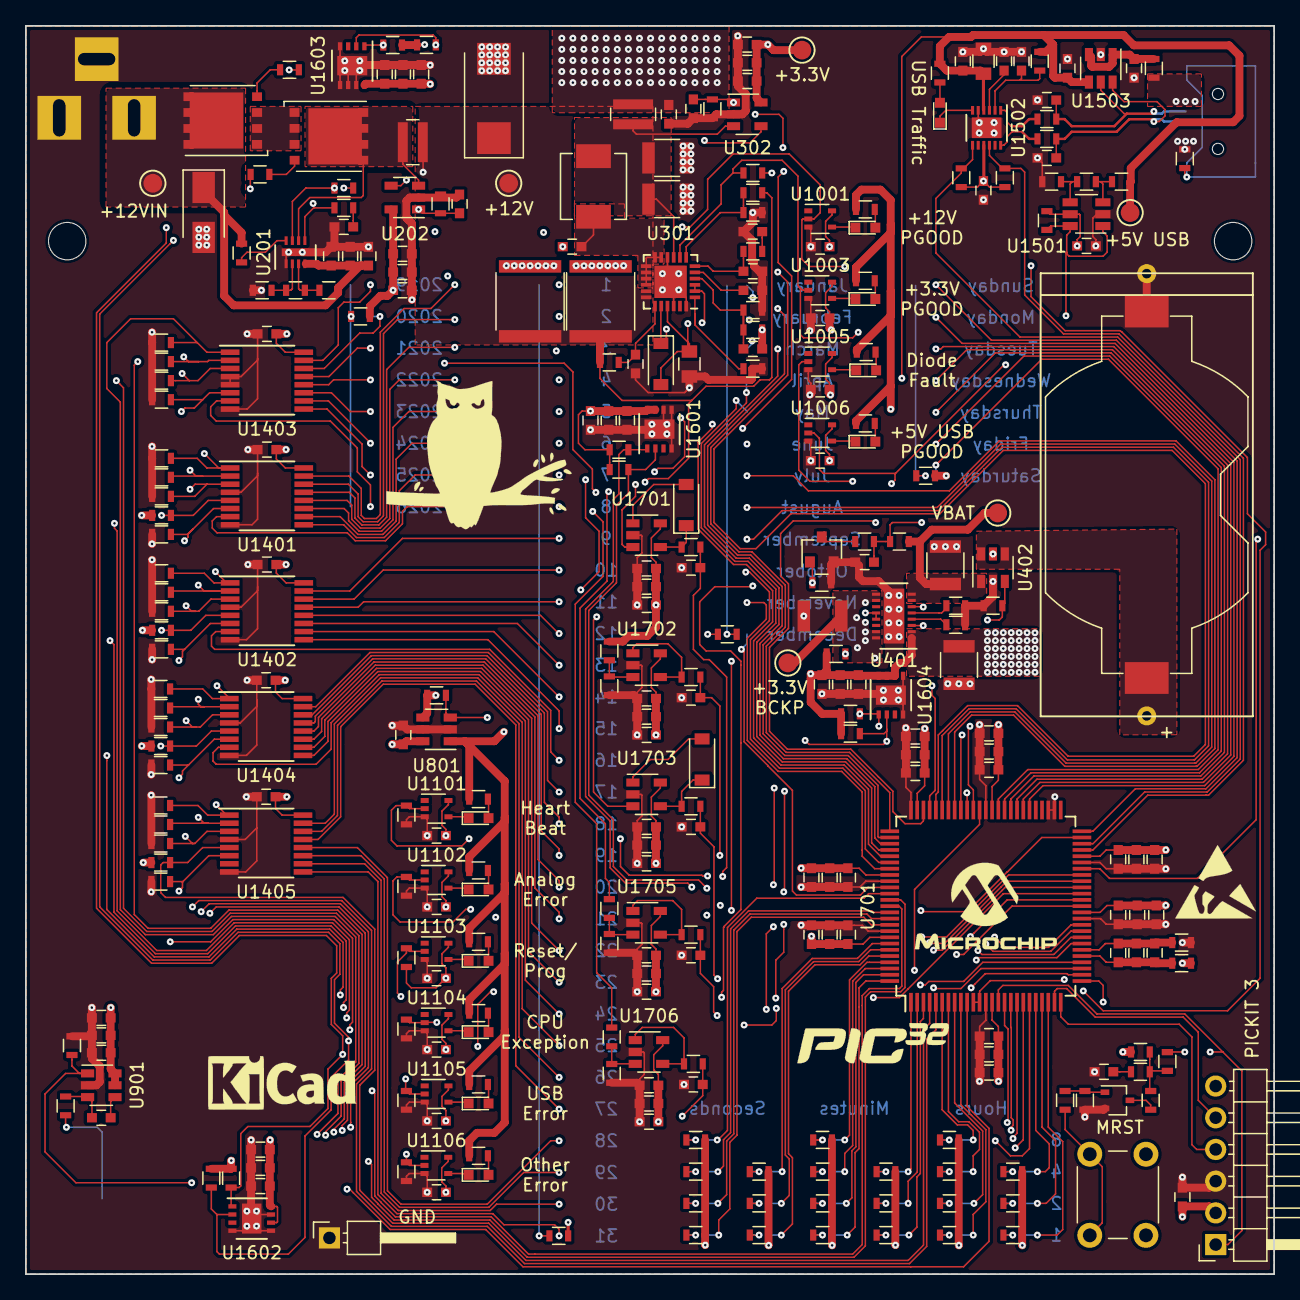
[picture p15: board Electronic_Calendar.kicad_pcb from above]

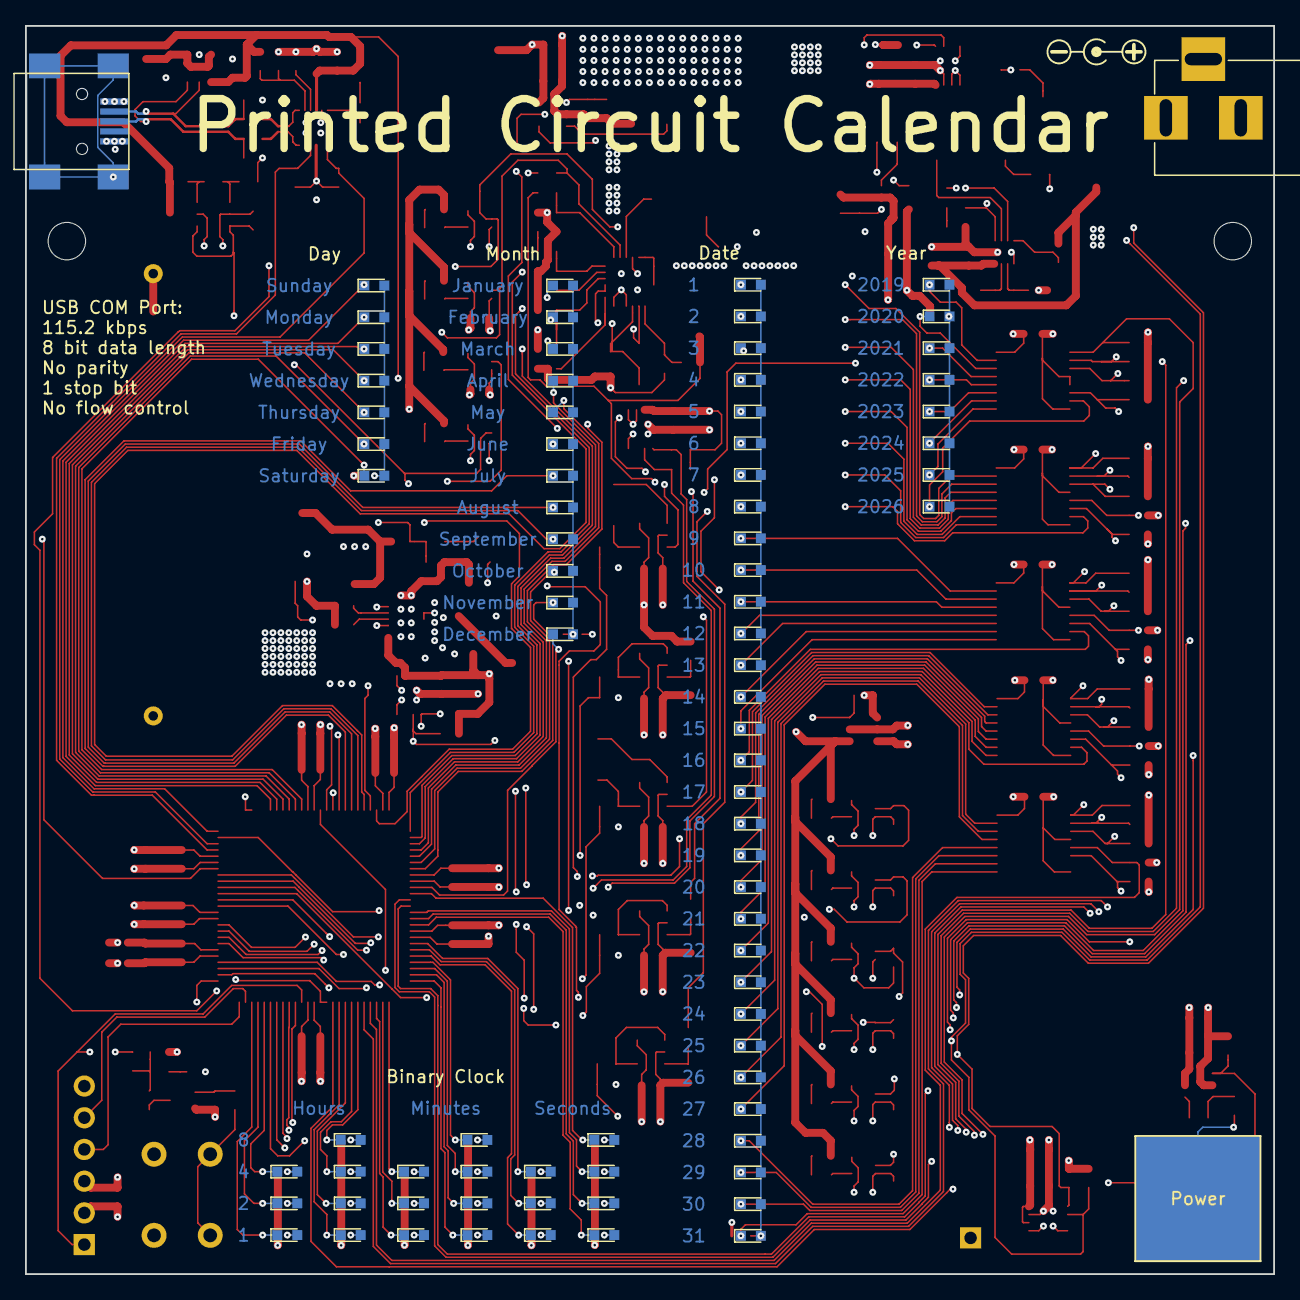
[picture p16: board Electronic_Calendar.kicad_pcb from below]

Board: 4 copper layers, 100.0 x 100.0 mm, 399 parts (82 on the bottom side), 229 nets.

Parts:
BT401: BR-2/3AE5SPN; BR-2_3AE5SPN
C201, C204, C205, C305, C307, C311, C316, C401, C601, C602, C801, C802, C807, C808, C813, C814, C819, C820, C825, C902, C1001, C1003, C1005, C1006, C1101, C1102, C1103, C1104, C1105, C1106, C1401, C1402, C1403, C1404, C1405, C1501, C1502, C1503, C1504, C1506, C1507, C1510, C1601, C1602, C1603, C1610, C1701, C1702, C1709, C1717, C1718: 0.1uF; C_0603
C202, C206, C304, C313, C803, C804, C809, C810, C815, C816, C821, C822, C901, C903, C1604, C1605, C1606, C1611, C1703, C1704, C1707, C1708, C1711, C1715, C1719, C1720, C1723, C1724: 10nF; C_0603
C203, C207, C208, C314, C317, C805, C806, C811, C812, C817, C818, C823, C824, C904, C1607, C1608, C1609, C1612, C1705, C1706, C1713, C1721, C1722: 1nF; C_0603
C209: 100uF; CP_Tantalum_Case-X_EIA-7343-43_Reflow
C301, C302: 22uF; C_2220
C306: 62pF; C_0603
C308, C310: 15pF; C_0603
C309: 2.2uF; C_0805
C312, C315, C402, C403, C404: 47uF; C_1210
C1505: 4.7uF; C_0805
C1508, C1509: 47pF; C_0603
D201: 24V; D_SMA
D301, D1601, D1602: MBR0530; D_SOD-123
D1001, D1003, D1006, D1101: Green; LED_0603
D1005, D1102, D1103, D1104, D1105, D1106, D1201, D1202, D1203, D1204, D1205, D1206, D1207, D1208, D1209, D1210, D1211, D1212, D1213, D1214, D1215, D1216, D1217, D1218, D1219, D1220, D1221, D1222, D1223, D1224, D1225, D1226, D1227, D1228, D1229, D1230, D1231, D1232, D1233, D1234, D1235, D1236, D1237, D1238, D1239, D1240, D1241, D1242, D1243, D1244, D1245, D1246, D1247, D1248, D1249, D1250, D1251, D1252, D1253, D1254, D1255, D1256, D1257, D1258, D1301, D1302, D1303, D1304, D1305, D1306, D1307, D1308, D1309, D1310, D1311, D1312, D1313, D1314, D1315, D1316, D1317, D1318, D1319, D1320, D1321: Red; LED_0603
D1501: Yellow; LED_0603
J201: +12V IN; BARREL_JACK
J601: PICKIT3; PICKIT3_Header
J1501: USB_B_Mini; USB_Mini-B
L301: 0.47uH; L_Vishay_IHLP-2020
L801, L802, L1501, L1502: 600R 0.5A; L_0603
Q201, Q202: IPC100N04S51R2ATMA1; TDSON-8-1
Q401: 2N7002; SOT-23
Q601: BSS214NW; SOT-323_SC-70
R201: 6.04M; R_0603
R202: 86.6k; R_0603
R203, R401, R402, R407: 243k; R_0603
R204, R302, R307, R310: 100k; R_0603
R205, R206, R304, R601: 10; R_0603
R207, R301, R403, R406, R602, R604, R801, R902, R1101, R1102, R1105, R1106, R1109, R1110, R1401, R1402, R1403, R1404, R1405, R1406, R1407, R1408, R1409, R1410, R1411, R1412, R1413, R1414, R1415, R1416, R1417, R1418, R1419, R1420, R1421, R1422, R1423, R1424, R1501, R1505, R1506, R1507, R1607, R1608, R1609, R1610, R1611, R1612, R1615, R1616, R1701, R1702, R1707, R1709, R1710: 10k; R_0603
R208: 5.1k; R_0603
R209, R309: 0.02; R_0612
R210: 249k; R_0603
R303, R308: 22.1k; R_0603
R305: 63.4k; R_0603
R306: 13.3k; R_0603
R404, R405, R901, R1703, R1704, R1705, R1711, R1712: 499; R_0603
R603: 100; R_0603
R605: 0; R_0603
R606, R1001, R1003, R1005, R1006, R1103, R1104, R1107, R1108, R1111, R1112, R1201, R1202, R1203, R1204, R1301, R1302, R1303, R1304, R1305, R1306, R1307, R1308, R1309, R1310, R1311, R1312, R1313, R1314, R1315, R1316, R1317, R1318, R1319, R1320, R1321, R1510: 1k; R_0603
R1502: 487k; R_0603
R1503: 6.04k; R_0603
R1504: 40.2k; R_0603
R1508, R1509: 27; R_0603
R1708: 1.2k; R_0603
SW601: MRST; SW_PUSH_6mm
SW901: Cap_Touch; Capacitive_Touch_Pad
TP201: TP; Pin_Header_Angled_1x01_Pitch2.54mm
TP203, TP204, TP301, TP401, TP402, TP1501: TP; Test_Point
U201: LTC4365DDB; DFN-8-1EP_2x3mm_Pitch0.5mm
U202, U302: INA138; SOT-23-5
U301: LTC3605A_UF; QFN-24-1EP_4x4mm_Pitch0.5mm
U401: LTC4415DHC; DFN-16-1EP_3x5mm_Pitch0.5mm
U402, U801: TPS22929D; SOT-23-6
U701: PIC32MZ2048EFG100_IPT; TQFP-100_14x14mm_Pitch0.5mm
U901: AT42QT1010-TSHR; SOT-23-6
U1001, U1003, U1006, U1101, U1102, U1103, U1104, U1105, U1106: 74LVC1G06; SOT-353_SC-70-5
U1005: 74LVC1G17; SOT-353_SC-70-5
U1401, U1402, U1403, U1404, U1405: 74HC138; TSSOP-16_4.4x5mm_Pitch0.65mm
U1501: LT6700-1-S6; TSOT-23-6
U1502: FT234XD; DFN-12-1EP_3x3mm_Pitch0.45mm
U1503: TPD3S014DBVR; SOT-23-6
U1601, U1602, U1603, U1604: MCP9804_DFN; DFN-8-1EP_3x3mm_Pitch0.65mm
U1701, U1702, U1703, U1705, U1706: OPA340NA; SOT-23-5

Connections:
+3.3VA: C820.1, C822.1, C824.1, L801.1, U701.30
+3.3V_BCKP: C404.1, C601.1, C801.1, C802.1, C803.1, C804.1, C805.1, C806.1, C807.1, C808.1, C809.1, C810.1, C811.1, C812.1, C813.1, C814.1, C815.1, C816.1, C817.1, C818.1, C819.1, C821.1, C823.1, J601.2, L801.2, R604.1, SW601.1, TP401.1, U401.9, U401.10, U401.15, U401.16, U701.14, U701.37, U701.46, U701.62, U701.74, U701.83, U701.93
+3.3V_STAT: R1001.1, R1003.1, R1005.1, R1006.1, R1103.1, R1104.1, R1107.1, R1108.1, R1111.1, R1112.1, U801.1
+3V3: C205.1, C206.1, C207.1, C310.1, C311.1, C313.1, C314.1, C316.1, C402.1, C825.1, C902.1, C903.1, C904.1, C1001.1, C1003.1, C1005.1, C1006.1, C1101.1, C1102.1, C1103.1, C1104.1, C1105.1, C1106.1, C1401.1, C1402.1, C1403.1, C1404.1, C1405.1, C1502.1, C1503.1, C1601.1, C1602.1, C1603.1, C1604.1, C1605.1, C1606.1, C1607.1, C1608.1, C1609.1, C1610.1, C1611.1, C1612.1, C1701.1, C1702.1, C1703.1, C1704.1, C1705.1, C1706.1, C1709.1, C1711.1, C1713.1, C1717.1, C1718.1, C1719.1, C1720.1, C1721.1, C1722.1, R207.1, R301.1, R307.1, R309.2, R406.1, R801.1, R1105.1, R1201.1, R1202.1, R1203.1, R1204.1, R1301.1, R1302.1, R1303.1, R1304.1, R1305.1, R1306.1, R1307.1, R1308.1, R1309.1, R1310.1, R1311.1, R1312.1, R1313.1, R1314.1, R1315.1, R1316.1, R1317.1, R1318.1, R1319.1, R1320.1, R1321.1, R1413.1, R1414.1, R1423.1, R1424.1, R1505.1, R1506.1, R1507.1, R1607.1, R1608.1, R1609.1, R1610.1, R1611.1, R1612.1, R1615.1, R1616.1, R1701.2, TP301.1, U202.5, U302.4, U302.5, U401.1, U401.2, U801.4, U801.6, U901.5, U901.6, U1001.5, U1003.5, U1005.5, U1006.5, U1101.5, U1102.5, U1103.5, U1104.5, U1105.5, U1106.5, U1401.16, U1402.16, U1403.16, U1404.16, U1405.16, U1501.5, U1502.9, U1601.7, U1601.8, U1602.6, U1602.8, U1603.8, U1604.6, U1604.7, U1604.8, U1701.5, U1702.5, U1703.5, U1705.5, U1706.5
+5V_USB: C1504.1, C1505.1, C1507.1, R1501.1, R1502.1, R1510.1, R1709.2, TP1501.1, U1502.4, U1503.4
+12V: C209.1, C301.1, C302.1, R209.2, R302.1, R304.1, R1707.2, TP204.1, U202.4, U301.17, U301.18
+12Vin: C201.1, C202.1, C203.1, D201.1, J201.1, Q201.5, R201.1, R204.1, TP203.1, U201.4
/USB UART Bridge/BRIDGE_USB+: R1508.2, U1502.12
/USB UART Bridge/BRIDGE_USB-: R1509.2, U1502.1
/USB UART Bridge/CONN_USB+: C1508.1, J1501.3, R1508.1, U1503.6
/USB UART Bridge/CONN_USB-: C1509.1, J1501.2, R1509.1, U1503.5
Analog_Error_LED: R1102.1, U701.34, U1102.2
Cap_Touch_Power: R902.1, U701.10, U901.1
Date_B0: R1401.1, R1402.1, R1415.1, R1416.1, U701.17, U1401.1, U1402.1, U1404.1, U1405.1
Date_B1: R1404.1, R1405.1, R1417.1, R1418.1, U701.16, U1401.2, U1402.2, U1404.2, U1405.2
Date_B2: R1407.1, R1408.1, R1419.1, R1420.1, U701.5, U1401.3, U1402.3, U1404.3, U1405.3
Date_Decode_Enable: R1410.1, R1411.1, R1412.1, R1421.1, R1422.1, U701.29, U1401.6, U1402.6, U1403.6, U1404.6, U1405.6
Exception_LED: R1106.1, U701.64, U1104.2
GND: BT401.2, C201.2, C202.2, C203.2, C204.2, C205.2, C206.2, C207.2, C208.2, C209.2, C301.2, C302.2, C304.2, C305.2, C306.2, C308.2, C309.2, C311.2, C312.2, C313.2, C314.2, C315.2, C316.2, C317.2, C401.2, C402.2, C403.2, C404.2, C601.2, C602.2, C801.2, C802.2, C803.2, C804.2, C805.2, C806.2, C807.2, C808.2, C809.2, C810.2, C811.2, C812.2, C813.2, C814.2, C815.2, C816.2, C817.2, C818.2, C819.2, C821.2, C823.2, C825.2, C902.2, C903.2, C904.2, C1001.2, C1003.2, C1005.2, C1006.2, C1101.2, C1102.2, C1103.2, C1104.2, C1105.2, C1106.2, C1401.2, C1402.2, C1403.2, C1404.2, C1405.2, C1501.2, C1502.2, C1503.2, C1504.2, C1505.2, C1506.2, C1507.2, C1508.2, C1509.2, C1510.2, C1601.2, C1602.2, C1603.2, C1604.2, C1605.2, C1606.2, C1607.2, C1608.2, C1609.2, C1610.2, C1611.2, C1612.2, C1701.2, C1702.2, C1703.2, C1704.2, C1705.2, C1706.2, C1707.2, C1708.2, C1709.2, C1711.2, C1713.2, C1715.2, C1717.2, C1718.2, C1719.2, C1720.2, C1721.2, C1722.2, C1723.2, C1724.2, D201.2, J201.2, J201.3, J601.3, J1501.5, L802.2, L1502.1, Q401.2, Q601.2, R203.2, R210.2, R303.2, R305.2, R308.2, R310.2, R403.2, R404.2, R405.2, R407.2, R602.2, R902.2, R1101.2, R1102.2, R1106.2, R1109.2, R1110.2, R1401.2, R1402.2, R1403.2, R1404.2, R1405.2, R1406.2, R1407.2, R1408.2, R1409.2, R1410.2, R1411.2, R1412.2, R1415.2, R1416.2, R1417.2, R1418.2, R1419.2, R1420.2, R1421.2, R1422.2, R1504.2, R1702.1, R1708.2, R1710.1, TP201.1, U201.1, U201.9, U202.2, U301.10, U301.22, U301.24, U301.25, U302.2, U401.17, U402.2, U402.5, U701.13, U701.36, U701.45, U701.52, U701.53, U701.63, U701.75, U701.84, U701.92, U801.2, U801.5, U901.2, U1001.3, U1003.3, U1005.3, U1006.3, U1101.3, U1102.3, U1103.3, U1104.3, U1105.3, U1106.3, U1401.4, U1401.8, U1402.4, U1402.8, U1403.4, U1403.5, U1403.8, U1404.4, U1404.8, U1405.4, U1405.8, U1501.2, U1502.5, U1502.13, U1503.2, U1601.4, U1601.5, U1601.6, U1601.9, U1602.4, U1602.5, U1602.7, U1602.9, U1603.4, U1603.5, U1603.6, U1603.7, U1603.9, U1604.4, U1604.5, U1604.9, U1701.2, U1702.2, U1703.2, U1705.2, U1706.2
GNDA: C820.2, C822.2, C824.2, L802.1, U701.31
Heartbeat_LED: R1101.1, U701.49, U1101.2
ICSPCLK: J601.5, U701.24
ICSPDAT: J601.4, U701.25
unnamed: BT401.1, U402.4, U402.6
unnamed: C204.1, R208.2
unnamed: C304.1, U301.5
unnamed: C305.1, R304.2, U301.19
unnamed: C306.1, R306.2
unnamed: C307.1, D301.1, U301.20
unnamed: C307.2, L301.1, U301.11, U301.12, U301.13, U301.14, U301.15, U301.16
unnamed: C308.1, R306.1, U301.6
unnamed: C309.1, D301.2, U301.2, U301.3, U301.21
unnamed: C310.2, R307.2, R308.1, U301.4
unnamed: C312.1, C315.1, L301.2, R309.1, U301.9, U302.3
unnamed: C602.1, R605.2
unnamed: C901.1, U901.4
unnamed: C901.2, R901.2, U901.3
unnamed: C1501.1, R1501.2, U1502.2
unnamed: C1506.1, U1502.3
unnamed: C1510.1, L1501.2, U1503.1, U1503.3
unnamed: D1001.1, U1001.4
unnamed: D1001.2, R1001.2
unnamed: D1003.1, U1003.4
unnamed: D1003.2, R1003.2
unnamed: D1005.1, U1005.4
unnamed: D1005.2, R1005.2
unnamed: D1006.1, U1006.4
unnamed: D1006.2, R1006.2
unnamed: D1101.1, U1101.4
unnamed: D1101.2, R1103.2
unnamed: D1102.1, U1102.4
unnamed: D1102.2, R1104.2
unnamed: D1103.1, U1103.4
unnamed: D1103.2, R1107.2
unnamed: D1104.1, U1104.4
unnamed: D1104.2, R1108.2
unnamed: D1105.1, U1105.4
unnamed: D1105.2, R1111.2
unnamed: D1106.1, U1106.4
unnamed: D1106.2, R1112.2
unnamed: D1201.2, D1202.2, D1203.2, D1204.2, D1205.2, D1206.2, D1207.2, D1208.2, D1209.2, D1210.2, D1211.2, D1212.2, R1201.2
unnamed: D1213.2, D1214.2, D1215.2, D1216.2, D1217.2, D1218.2, D1219.2, D1220.2, D1221.2, D1222.2, D1223.2, D1224.2, D1225.2, D1226.2, D1227.2, D1228.2, D1236.2, D1237.2, D1238.2, D1239.2, D1240.2, D1241.2, D1242.2, D1243.2, D1244.2, D1245.2, D1246.2, D1247.2, D1248.2, D1249.2, D1250.2, R1202.2
unnamed: D1229.2, D1230.2, D1231.2, D1251.2, D1252.2, D1253.2, D1254.2, R1203.2
unnamed: D1232.2, D1233.2, D1234.2, D1235.2, D1255.2, D1256.2, D1257.2, D1258.2, R1204.2
unnamed: D1301.2, R1301.2
unnamed: D1302.2, R1302.2
unnamed: D1303.2, R1303.2
unnamed: D1304.2, R1304.2
unnamed: D1305.2, R1305.2
unnamed: D1306.2, R1306.2
unnamed: D1307.2, R1307.2
unnamed: D1308.2, R1308.2
unnamed: D1309.2, R1309.2
unnamed: D1310.2, R1310.2
unnamed: D1311.2, R1311.2
unnamed: D1312.2, R1312.2
unnamed: D1313.2, R1313.2
unnamed: D1314.2, R1314.2
unnamed: D1315.2, R1315.2
unnamed: D1316.2, R1316.2
unnamed: D1317.2, R1317.2
unnamed: D1318.2, R1318.2
unnamed: D1319.2, R1319.2
unnamed: D1320.2, R1320.2
unnamed: D1321.2, R1321.2
unnamed: D1501.2, R1510.2
unnamed: D1601.1, R1703.2, U1701.4
unnamed: D1601.2, U1701.1
unnamed: D1602.1, R1705.2, U1703.4
unnamed: D1602.2, U1703.1
unnamed: J1501.1, L1501.1
unnamed: J1501.6, L1502.2
unnamed: Q201.1, Q201.2, Q201.3, Q202.1, Q202.2, Q202.3
unnamed: Q201.4, R205.2
unnamed: Q202.4, R206.1
unnamed: Q202.5, R209.1, U201.6, U202.3
unnamed: Q401.3, R402.2
unnamed: Q601.1, R601.2, R602.1
unnamed: Q601.3, R603.2
unnamed: R201.2, R202.1, U201.3
unnamed: R202.2, R203.1, U201.2
unnamed: R204.2, U201.8
unnamed: R205.1, R206.2, R208.1, U201.5
unnamed: R302.2, R303.1, U301.7
unnamed: R305.1, U301.1
unnamed: R404.1, U401.4
unnamed: R405.1, U401.5
unnamed: R601.1, SW601.2
unnamed: R603.1, R604.2, R605.1, R606.2
unnamed: R901.1, SW901.1
unnamed: R1502.2, R1503.1, U1501.3
unnamed: R1503.2, R1504.1, U1501.4
unnamed: R1701.1, R1702.2, U1702.3
unnamed: R1704.2, U1702.1, U1702.4
unnamed: R1707.1, R1708.1, U1705.3
unnamed: R1709.1, R1710.2, U1706.3
unnamed: R1711.2, U1705.1, U1705.4
unnamed: R1712.2, U1706.1, U1706.4
Other_Error_LED: R1110.1, U701.87, U1106.2
POS3P3_ADC: C1708.1, R1704.1, U701.32
POS3P3_ISNS: C317.1, R310.1, U302.1, U1703.3
POS3P3_ISNS_ADC: C1715.1, R1705.1, U701.38
POS3P3_PGOOD: R301.2, U301.8, U401.3, U401.6, U701.72, U1003.2
POS5_USB_ADC: C1724.1, R1712.1, U701.26
POS5_USB_PGOOD: R1507.2, U701.73, U1006.2, U1501.1, U1501.6
POS12_ADC: C1723.1, R1711.1, U701.27
POS12_ISNS: C208.1, R210.1, U202.1, U1701.3
POS12_ISNS_ADC: C1707.1, R1703.1, U701.33
POS12_PGOOD: R207.2, U201.7, U701.11, U701.12, U1001.2
Reset_LED: R1105.2, U701.28, U1103.2
STATUS_LED_ENABLE: R801.2, U701.35, U801.3
TEMP_I2C_SCL: R1610.2, R1611.2, R1612.2, R1616.2, U701.66, U1601.2, U1602.2, U1603.2, U1604.2
TEMP_I2C_SDA: R1607.2, R1608.2, R1609.2, R1615.2, U701.67, U1601.1, U1602.1, U1603.1, U1604.1
USB_Error_LED: R1109.1, U701.88, U1105.2
USB_UART_RX: R1506.2, U701.48, U1502.7
USB_UART_TX: R1505.2, U701.47, U1502.10
VBAT: C403.1, R401.1, TP402.1, U401.7, U401.8, U402.1
VBAT_ADC: C401.1, R401.2, R402.1, U701.44
VBAT_ADC_EN: Q401.1, R403.1, U701.40
Year_B0: R1403.1, U701.20, U1403.1
Year_B1: R1406.1, U701.18, U1403.2
Year_B2: R1409.1, U701.19, U1403.3
~APR_LED: D1208.1, U701.78
~AUG_LED: D1210.1, U701.69
~DEC_LED: D1212.1, U701.85
~DIODE_FAULT: R406.2, U401.12, U401.13, U701.39, U1005.2
~Date1_LED: D1213.1, U1401.15
~Date2_LED: D1236.1, U1401.14
~Date3_LED: D1214.1, U1401.13
~Date4_LED: D1237.1, U1401.12
~Date5_LED: D1215.1, U1401.11
~Date6_LED: D1238.1, U1401.10
~Date7_LED: D1216.1, U1401.9
~Date8_LED: D1239.1, U1401.7
~Date9_LED: D1217.1, U1402.15
~Date10_LED: D1240.1, U1402.14
~Date11_LED: D1218.1, U1402.13
~Date12_LED: D1241.1, U1402.12
~Date13_LED: D1219.1, U1402.11
~Date14_LED: D1242.1, U1402.10
~Date15_LED: D1220.1, U1402.9
~Date16_LED: D1243.1, U1402.7
~Date17_LED: D1221.1, U1404.15
~Date18_LED: D1244.1, U1404.14
~Date19_LED: D1222.1, U1404.13
~Date20_LED: D1245.1, U1404.12
~Date21_LED: D1223.1, U1404.11
~Date22_LED: D1246.1, U1404.10
~Date23_LED: D1224.1, U1404.9
~Date24_LED: D1247.1, U1404.7
~Date25_LED: D1225.1, U1405.15
~Date26_LED: D1248.1, U1405.14
~Date27_LED: D1226.1, U1405.13
~Date28_LED: D1249.1, U1405.12
~Date29_LED: D1227.1, U1405.11
~Date30_LED: D1250.1, U1405.10
~Date31_LED: D1228.1, U1405.9
~Date_Decode_1: R1413.2, U701.41, U1401.5
~Date_Decode_2: R1414.2, U701.42, U1402.5
~Date_Decode_3: R1423.2, U701.43, U1404.5
~Date_Decode_4: R1424.2, U701.4, U1405.5
~FEB_LED: D1207.1, U701.76
~FRI_LED: D1231.1, U701.60
~Hours0_LED: D1301.1, U701.6
~Hours1_LED: D1313.1, U701.21
~Hours2_LED: D1302.1, U701.7
~Hours3_LED: D1314.1, U701.22
~Hours4_LED: D1303.1, U701.8
~Hours5_LED: D1315.1, U701.23
~Hours6_LED: D1304.1, U701.9
~JAN_LED: D1201.1, U701.71
~JUL_LED: D1204.1, U701.68
~JUN_LED: D1209.1, U701.80
~MAR_LED: D1202.1, U701.77
~MAY_LED: D1203.1, U701.79
~MCLR: J601.1, R606.1, U701.15
~MON_LED: D1229.1, U701.56
~Minutes0_LED: D1305.1, U701.97
~Minutes1_LED: D1316.1, U701.1
~Minutes2_LED: D1306.1, U701.98
~Minutes3_LED: D1317.1, U701.2
~Minutes4_LED: D1307.1, U701.99
~Minutes5_LED: D1318.1, U701.3
~Minutes6_LED: D1308.1, U701.100
~NOV_LED: D1206.1, U701.82
~OCT_LED: D1211.1, U701.81
~SAT_LED: D1254.1, U701.61
~SEP_LED: D1205.1, U701.70
~SUN_LED: D1251.1, U701.50
~Seconds0_LED: D1309.1, U701.86
~Seconds1_LED: D1319.1, U701.94
~Seconds2_LED: D1310.1, U701.89
~Seconds3_LED: D1320.1, U701.95
~Seconds4_LED: D1311.1, U701.90
~Seconds5_LED: D1321.1, U701.96
~Seconds6_LED: D1312.1, U701.91
~THR_LED: D1253.1, U701.59
~TUE_LED: D1252.1, U701.57
~USB_TRAFFIC: D1501.1, U1502.6
~VBAT_ISOLATE: R407.1, U402.3, U701.65
~WED_LED: D1230.1, U701.58
~Year2019_LED: D1232.1, U1403.15
~Year2020_LED: D1255.1, U1403.14
~Year2021_LED: D1233.1, U1403.13
~Year2022_LED: D1256.1, U1403.12
~Year2023_LED: D1234.1, U1403.11
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

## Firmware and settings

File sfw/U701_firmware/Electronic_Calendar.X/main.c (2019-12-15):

/*
 * File:   main.c
 * Author: Drew Maatman
 *
 * Created on July 19, 2019, 9:00 PM
 */


#include <xc.h>
#include <stdio.h>
#include <stdbool.h>
#include <string.h>

#include "configuration.h"
#include "32mz_interrupt_control.h"
#include "cause_of_reset.h"
#include "pin_macros.h"
#include "device_control.h"
#include "gpio_setup.h"
#include "prefetch.h"
#include "watchdog_timer.h"
#include "heartbeat_timer.h"
#include "usb_uart.h"
#include "usb_uart_rx_lookup_table.h"
#include "terminal_control.h"
#include "power_saving.h"
#include "rtcc.h"
#include "binary_clock.h"
#include "calendar_leds.h"
#include "adc.h"
#include "telemetry.h"
#include "temp_i2c.h"
#include "mcp9804_temp_sensor.h"
#include "misc_IO_functions.h"

void main(void) {
    
    // Disable global interrupts so clocks can be initialized properly
    disableGlobalInterrupts();
    
    // Save the cause of the most recent device reset
    // This also checks for configuration errors
    reset_cause = getResetCause();
    
    // Initialize system clocks
    clockInitialize();
    
    // Configure interrupt controller
    interruptControllerInitialize();
    
    // Enable Global Interrupts
    enableGlobalInterrupts();
    
    // Initialize GPIO pins to startup settings
    gpioInitialize();
    
    // Enable status LED supply rail
    STATUS_LED_ENABLE_PIN = HIGH;
    
    // Setup USB UART debugging
    usbUartInitialize();
    
    // Clear the terminal
    terminalClearScreen();
    terminalSetCursorHome();
    
    terminalTextAttributesReset();
    terminalTextAttributes(GREEN_COLOR, BLACK_COLOR, BOLD_FONT);
    printf("Electronic Calendar\r\n");
    printf("Created by Drew Maatman, 2019\r\n");
    terminalTextAttributesReset();
    
    // Print cause of reset
    if (    reset_cause == Undefined ||
            reset_cause == Primary_Config_Registers_Error ||
            reset_cause == Primary_Secondary_Config_Registers_Error ||
            reset_cause == Config_Mismatch ||
            reset_cause == DMT_Reset ||
            reset_cause == WDT_Reset ||
            reset_cause == Software_Reset ||
            reset_cause == External_Reset ||
            reset_cause == BOR_Reset) {
    
        terminalTextAttributes(RED_COLOR, BLACK_COLOR, NORMAL_FONT);
        
    }
    
    else {
     
        terminalTextAttributes(GREEN_COLOR, BLACK_COLOR, NORMAL_FONT);
        
    }
    
    // only clear persistent error flags if we've seen a POR... keep old values after other resets
    if (reset_cause == POR_Reset) clearErrorHandler();
    
    printf("\r\nCause of most recent device reset: %s\r\n\r\n", getResetCauseString(reset_cause));
    terminalTextAttributesReset();
    terminalTextAttributes(GREEN_COLOR, BLACK_COLOR, NORMAL_FONT);
    printf("Beginning Peripheral Initialization:\r\n");
    printf("    Oscillators, Phase-Locked Loop, and System Clocks Initialized\n\r");
    printf("    Interrupt Controller Initialized, Global Interrupts Enabled\n\r");
    printf("    GPIO Pins Initialized\n\r");
    printf("    Status LEDs Enabled\r\n");
    printf("    USB UART Initialized, DMA buffer method used\n\r");
    
    // Setup error handling
    errorHandlerInitialize();
    printf("    Error Handler Initialized\n\r");
    
    
    // Setup heartbeat timer
    heartbeatTimerInitialize();
    printf("    Heartbeat Timer Initialized\n\r");
    
    // Setup prefetch module
    prefetchInitialize();
    printf("    CPU Instruction Prefetch Module Enabled\r\n");
    
    // Disable unused peripherals for power savings
    PMDInitialize();
    printf("    Unused Peripheral Modules Disabled\n\r");
    
    // Setup the watchdog timer
    watchdogTimerInitialize();
    printf("    Watchdog Timer Initialized\n\r");
    
    // Setup the real time clock-calendar
    rtccInitialize();
    if (reset_cause == POR_Reset) rtccClear();
    printf("    Real Time Clock-Calendar Initialized\r\n");
    
    // setup the ADC modules
    ADCInitialize();
    telemetryInitialize();
    printf("    Analog to Digital Converters, Telemetry Initialized\r\n");
    
    // setup temperature sensor I2C bus
    TEMP_I2C_Initialize();
    printf("    Temperature Sensor I2C Bus Initialized\r\n");
    MCP9804TempSensorInitialize();
    printf("    I2C Digital Temperature Sensors Initialized\r\n");
    
    // setup power toggle cap touch button
    capTouchPowerInitialize();
    printf("    Power Toggle Capacitive Pushbutton Initialized\r\n");
    
    // Disable RESET LED
    RESET_LED_PIN = LOW;
    printf("    Reset LED Disabled\r\n");
    
    // Enable date decoding
    DATE_DECODE_ENABLE_PIN = HIGH;
    printf("    Date Decoding Enabled\r\n");
    
    terminalTextAttributesReset();
    terminalTextAttributes(YELLOW_COLOR, BLACK_COLOR, NORMAL_FONT);
    printf("\n\rType 'Help' for list of supported commands\n\r\n\r");
    terminalTextAttributesReset();
    
    clockFailCheck();
    
    // Main loop
    while (true) {
        
        // check to see if a clock fail has occurred and latch it
        clockFailCheck();
        
        // check to see if a PGOOD fault has occurred and latch it
        powerGoodCheck();
        
        // convert raw temp results into floating point telemetry
        MCP9804BatchConvert();
        
        // set LEDs if changes are pending
        if (led_update_request_flag) {
         
            // update values displayed on binary clock LEDs
            updateBinaryClockLEDs(rtcc_shadow.hours, rtcc_shadow.minutes, rtcc_shadow.seconds);

            // update value displayed on month LEDs
            updateMonthLEDs(rtcc_shadow.month);

            // update value displayed on weekday LEDs
            updateWeekdayLEDs(rtcc_shadow.weekday);

            // update value displayed on year LEDs
            updateYearLEDs(rtcc_shadow.year);
            
            // update value displayed on day LEDs
            updateDateLEDs(rtcc_shadow.day);
            
            led_update_request_flag = 0;
            
        }
        
        // check to see if we have a new usb uart string to parse
        // if (usb_uart_rx_parse_request && strlen(usb_uart_rx_buffer) > 2) {
        if (usb_uart_rx_parse_request) {
            // Determine length of received string
            uint32_t length = strlen(usb_uart_rx_buffer);
            
            // parse received string
            usbUartRxLUTInterface(usb_uart_rx_buffer);
            usb_uart_rx_parse_request = 0;
            
            // clear rx buffer
            uint32_t index;
            for (index = 0; index < length; index++) {
                usb_uart_rx_buffer[index] = '\0';
            }
            
        }
        
        // if we need to grab new temp sensor data, do it
        if (MCP9804_start_flag) MCP9804AcquisitionHandler();
        
        // update minimum and maximum measured telemetry
        if (telemetry_update_flag_adc && telemetry_update_flag_i2c) telemetryUpdateExtremes();
        
        // update error LEDs if needed
        if (update_error_leds_flag) updateErrorLEDs();
        
        // if we need to shut down due to a pushbutton toggle
        if (pushbutton_shutdown_request) capToughPowerToggleShutdown();
        
        // if we need to wakeup do to a pushbutton toggle, wakey wakey eggs and bakey
        if (pushbutton_wakeup_request) capToughPowerToggleWakeup();
        
    }
    
}

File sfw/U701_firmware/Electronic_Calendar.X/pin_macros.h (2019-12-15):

/* ************************************************************************** */
/** Descriptive File Name

  @Company
    Company Name

  @File Name
    filename.h

  @Summary
    Brief description of the file.

  @Description
    Describe the purpose of this file.
 */
/* ************************************************************************** */

#ifndef _PIN_MACROS_H    /* Guard against multiple inclusion */
#define _PIN_MACROS_H

#include <xc.h>

#define HIGH    1
#define LOW     0

// These pin macros allow for easier manipulation of GPIO with matching
// signal names from the hardware schematic

// Port A
#define DATE_B0_PIN                 LATAbits.LATA0
#define nTHUR_LED_PIN               LATAbits.LATA2
#define nFRI_LED_PIN                LATAbits.LATA3
#define nSAT_LED_PIN                LATAbits.LATA4
#define nMINUTES3_LED_PIN           LATAbits.LATA5
#define nSECONDS2_LED_PIN           LATAbits.LATA6
#define nSECONDS4_LED_PIN           LATAbits.LATA7
#define RESET_LED_PIN               LATAbits.LATA9
#define DATE_DECODE_ENABLE_PIN      LATAbits.LATA10

// Port B
#define nHOURS5_LED_PIN             LATBbits.LATB2
#define nHOURS3_LED_PIN             LATBbits.LATB3
#define nHOURS1_LED_PIN             LATBbits.LATB4
#define YEAR_B0_PIN                 LATBbits.LATB5
#define ANALOG_ERROR_LED_PIN        LATBbits.LATB10
#define STATUS_LED_ENABLE_PIN       LATBbits.LATB11
#define nDATE_DECODE_1_PIN          LATBbits.LATB12
#define nDATE_DECODE_2_PIN          LATBbits.LATB13
#define nDATE_DECODE_3_PIN          LATBbits.LATB14

// Port C
#define nHOURS0_LED_PIN             LATCbits.LATC1
#define nHOURS2_LED_PIN             LATCbits.LATC2
#define nHOURS4_LED_PIN             LATCbits.LATC3
#define nHOURS6_LED_PIN             LATCbits.LATC4
#define HEARTBEAT_LED_PIN           LATCbits.LATC12
#define POS3P3_PGOOD_PIN            PORTCbits.RC13
#define POS5_USB_PGOOD_PIN          PORTCbits.RC14
#define nSUN_LED_PIN                LATCbits.LATC15

// Port D
#define nJAN_LED_PIN                LATDbits.LATD0
#define nFEB_LED_PIN                LATDbits.LATD1
#define nMAR_LED_PIN                LATDbits.LATD2
#define nAPR_LED_PIN                LATDbits.LATD3
#define nOCT_LED_PIN                LATDbits.LATD4
#define nNOV_LED_PIN                LATDbits.LATD5
#define nJUL_LED_PIN                LATDbits.LATD9
#define nAUG_LED_PIN                LATDbits.LATD10
#define nSEP_LED_PIN                LATDbits.LATD11
#define nMAY_LED_PIN                LATDbits.LATD12
#define nJUN_LED_PIN                LATDbits.LATD13

// Port E
#define nSECONDS6_LED_PIN           LATEbits.LATE0
#define nSECONDS1_LED_PIN           LATEbits.LATE1
#define nMINUTES2_LED_PIN           LATEbits.LATE2
#define nMINUTES4_LED_PIN           LATEbits.LATE3
#define nMINUTES6_LED_PIN           LATEbits.LATE4
#define nMINUTES5_LED_PIN           LATEbits.LATE5
#define nDATE_DECODE_4_PIN          LATEbits.LATE6
#define DATE_B2_PIN                 LATEbits.LATE7
#define YEAR_B1_PIN                 LATEbits.LATE8
#define YEAR_B2_PIN                 LATEbits.LATE6

// Port F
#define nDEC_LED_PIN                LATFbits.LATF0
#define nSECONDS0_LED_PIN           LATFbits.LATF1
#define nTUE_LED_PIN                LATFbits.LATF2
#define nMON_LED_PIN                LATFbits.LATF3
#define EXCEPTION_LED_PIN           LATFbits.LATF4
#define nVBAT_ISOLATE_PIN           LATFbits.LATF5
#define nWED_LED_PIN                LATFbits.LATF8
#define VBAT_ADC_ENABLE_PIN         LATFbits.LATF12
#define nDIODE_FAULT_PIN            PORTFbits.RF13

// Port G
#define USB_ERROR_LED_PIN           LATGbits.LATG0
#define OTHER_ERROR_LED_PIN         LATGbits.LATG1
#define CAP_TOUCH_POWER_PIN         PORTGbits.RG6
#define POS12_PGOOD_PIN             PORTGbits.RG7
#define DATE_B1_PIN                 LATGbits.LATG9
#define nSECONDS5_LED_PIN           LATGbits.LATG12
#define nMINUTES0_LED_PIN           LATGbits.LATG13
#define nSECONDS3_LED_PIN           LATGbits.LATG14
#define nMINUTES1_LED_PIN           LATGbits.LATG15

#endif /* _PIN_MACROS_H */

/* *****************************************************************************
 End of File
 */

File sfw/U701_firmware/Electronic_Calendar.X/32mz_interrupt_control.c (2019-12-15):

#include <xc.h>
#include <stdio.h>

#include "32mz_interrupt_control.h"
#include "terminal_control.h"

// This function configures the system for multi-interrupt operation and
// assigns shadow registers sets to priority level ISRs
void interruptControllerInitialize(void) {
 
    // Enable multi-vector interrupt mode
    INTCONbits.MVEC = 1;
    
    // Assign shadow register sets to interrupt priorities
    // assign shadow set #7-#1 to priority level #7-#1 ISRs
    PRISS = 0x76543210;

}

// This function enables global interrupts
void enableGlobalInterrupts(void) {
 
    // This is built into the XC32 compiler
    __builtin_enable_interrupts();
    
}

// This function disables global interrupts
void disableGlobalInterrupts(void) {
 
    // This is built into the XC32 compiler
    __builtin_disable_interrupts();
    
}

// This function returns the state of global interrupt enable
// Returns 0 if global interrupts are disabled
// returns 1 if global interrupts are enabled
uint8_t getGlobalInterruptsState(void) {
 
    return __builtin_get_isr_state();
    
}

// This function explicitly sets the state of global interrupts
void setGlobalInterruptsState(uint8_t input_state) {

    __builtin_set_isr_state(input_state);
    
}


// This function allows for the setting/clearing of a given interrupt
// It manipulates that interrupt's 'Interrupt Enable' bit
void setInterruptEnable(interrupt_source_t input_interrupt, uint8_t input_state) {
 
    // Mask off anything larger than 1 to 1
    // input_state = input_state >= 1;
    
    // Decide which interrupt control bits to manipulate based on which interrupt
    // is being enabled or disabled
    switch (input_interrupt) {
        
        case Core_Timer_Interrupt:
            IEC0bits.CTIE = input_state;
            break;
            
        case Core_Software_Interrupt_0:
            IEC0bits.CS0IE = input_state;
            break;
            
        case Core_Software_Interrupt_1:
            IEC0bits.CS1IE = input_state;
            break;
            
        case External_Interrupt_0:
            IEC0bits.INT0IE = input_state;
            break;
            
        case Timer1:
            IEC0bits.T1IE = input_state;
            break;
            
        case Input_Capture_1_Error:
            IEC0bits.IC1EIE = input_state;
            break;
            
        case Input_Capture_1:
            IEC0bits.IC1IE = input_state;
            break;
            
        case Output_Compare_1:
            IEC0bits.OC1IE = input_state;
            break;
            
        case External_Interrupt_1:
            IEC0bits.INT1IE = input_state;
            break;
            
        case Timer2:
            IEC0bits.T2IE = input_state;
            break;
            
        case Input_Capture_2_Error:
            IEC0bits.IC2EIE = input_state;
            break;
            
        case Input_Capture_2:
            IEC0bits.IC2IE = input_state;
            break;
            
        case Output_Compare_2:
            IEC0bits.OC2IE = input_state;
            break;
            
        case External_Interrupt_2:
            IEC0bits.INT2IE = input_state;
            break;
            
        case Timer3:
            IEC0bits.T3IE = input_state;
            break;
            
        case Input_Capture_3_Error:
            IEC0bits.IC3EIE = input_state;
            break;
            
        case Input_Capture_3:
            IEC0bits.IC3IE = input_state;
            break;
            
        case Output_Compare_3:
            IEC0bits.OC3IE = input_state;
            break;
            
        case External_Interrupt_3:
            IEC0bits.INT3IE = input_state;
            break;
            
        case Timer4:
            IEC0bits.T4IE = input_state;
            break;
            
        case Input_Capture_4_Error:
            IEC0bits.IC4EIE = input_state;
            break;
            
        case Input_Capture_4:
            IEC0bits.IC4IE = input_state;
            break;
            
        case Output_Compare_4:
            IEC0bits.OC4IE = input_state;
            break;
            
        case External_Interrupt_4:
            IEC0bits.INT4IE = input_state;
            break;
            
        case Timer5:
            IEC0bits.T5IE = input_state;
            break;
            
        case Input_Capture_5_Error:
            IEC0bits.IC5EIE = input_state;
            break;
            
        case Input_Capture_5:
            IEC0bits.IC5IE = input_state;
            break;
            
        case Output_Compare_5:
            IEC0bits.OC5IE = input_state;
            break;
            
        case Timer6:
            IEC0bits.T6IE = input_state;
            break;
            
        case Input_Capture_6_Error:
            IEC0bits.IC6EIE = input_state;
            break;
            
        case Input_Capture_6:
            IEC0bits.IC6IE = input_state;
            break;
            
        case Output_Compare_6:
            IEC0bits.OC6IE = input_state;
            break;
            
        case Timer7:
            IEC1bits.T7IE = input_state;
            break;
            
        case Input_Capture_7_Error:
            IEC1bits.IC7EIE = input_state;
            break;
            
        case Input_Capture_7:
            IEC1bits.IC7IE = input_state;
            break;
            
        case Output_Compare_7:
            IEC1bits.OC7IE = input_state;
            break;
            
        case Timer8:
            IEC1bits.T8IE = input_state;
            break;
            
        case Input_Capture_8_Error:
            IEC1bits.IC8EIE = input_state;
            break;
            
        case Input_Capture_8:
            IEC1bits.IC8IE = input_state;
            break;
            
        case Output_Compare_8:
            IEC1bits.OC8IE = input_state;
            break;
            
        case Timer9:
            IEC1bits.T9IE = input_state;
            break;
            
        case Input_Capture_9_Error:
            IEC1bits.IC9EIE = input_state;
            break;
            
        case Input_Capture_9:
            IEC1bits.IC9IE = input_state;
            break;
            
        case Output_Compare_9:
            IEC1bits.OC9IE = input_state;
            break;
            
        case ADC_Global_Interrupt:
            IEC1bits.ADCIE = input_state;
            break;
            
        case ADC_FIFO_Data_Ready_Interrupt:
            IEC1bits.ADCFIFOIE = input_state;
            break;
            
        case ADC_Digital_Comparator_1:
            IEC1bits.ADCDC1IE = input_state;
            break;
        
        case ADC_Digital_Comparator_2:
            IEC1bits.ADCDC2IE = input_state;
            break;
            
        case ADC_Digital_Comparator_3:
            IEC1bits.ADCDC3IE = input_state;
            break;
            
        case ADC_Digital_Comparator_4:
            IEC1bits.ADCDC4IE = input_state;
            break;
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

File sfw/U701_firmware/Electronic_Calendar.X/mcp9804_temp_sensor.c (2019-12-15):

#include "mcp9804_temp_sensor.h"

#include "temp_i2c.h"

#include "error_handler.h"

#include "telemetry.h"

// This function initializes the three temperature sensors
void MCP9804TempSensorInitialize(void) {
    
    // Write config data to config register on input temp sensor
    uint8_t length;
    uint8_t output_data_array[3];
    output_data_array[0] = MCP9804_CONFIG_REG;
    output_data_array[1] = MCP9804_CONFIG_MSB;
    output_data_array[3] = MCP9804_CONFIG_LSB;
    length = 3;    
    TEMP_I2C_MasterWrite(output_data_array, length, INPUT_TEMP_SENS_ADDR, &TEMP_I2C_STATUS);
    while(TEMP_I2C_STATUS == TEMP_I2C_MESSAGE_PENDING);
    if (TEMP_I2C_STATUS != TEMP_I2C_MESSAGE_COMPLETE) error_handler.flags.temp_i2c_stall = 1;
    
    // Write config data to config register on pos3p3 power supply temp sensor
    TEMP_I2C_MasterWrite(output_data_array, length, POS3P3_TEMP_SENS_ADDR, &TEMP_I2C_STATUS);
    while(TEMP_I2C_STATUS == TEMP_I2C_MESSAGE_PENDING);
    if (TEMP_I2C_STATUS != TEMP_I2C_MESSAGE_COMPLETE) error_handler.flags.temp_i2c_stall = 1;
    
    // Write config data to config register on ambient temp sensor
    TEMP_I2C_MasterWrite(output_data_array, length, AMB_TEMP_SENS_ADDR, &TEMP_I2C_STATUS);
    while(TEMP_I2C_STATUS == TEMP_I2C_MESSAGE_PENDING);
    if (TEMP_I2C_STATUS != TEMP_I2C_MESSAGE_COMPLETE) error_handler.flags.temp_i2c_stall = 1;
    
    // Write config data to config register on bckp temp sensor
    TEMP_I2C_MasterWrite(output_data_array, length, BCKP_TEMP_SENS_ADDR, &TEMP_I2C_STATUS);
    while(TEMP_I2C_STATUS == TEMP_I2C_MESSAGE_PENDING);
    if (TEMP_I2C_STATUS != TEMP_I2C_MESSAGE_COMPLETE) error_handler.flags.temp_i2c_stall = 1;
    
}

// this function converts the ray two byte data return from MCP9804 to a double representing temperature
double MCP9804BytesToFloat(uint8_t input_array[2]) {
    
    input_array[0] = input_array[0] & 0x1F;
    // if we read a negative temperature
    if ((input_array[0] & 0x10) == 0x10) {

        input_array[0] = input_array[0] & 0x0F; //Clear SIGN
        // convert to floating point number
        return 256.0 - ((input_array[0] * 16.0) + (input_array[1] / 16.0));
        
    }
    
    // else if we read a positive temperature
    else {
     
        return ((input_array[0] * 16.0) + (input_array[1] / 16.0));
        
    }

}

// This function accesses temperature sensor data over I2C
void MCP9804AcquisitionHandler(void) {
    
    if (TEMP_I2C_STATUS != TEMP_I2C_MESSAGE_COMPLETE) {
        
        // log the fault
        error_handler.flags.temp_i2c_stall = 1;
        
        // reset the I2C controller if it's enabled
        if (getTempI2COnState) tempI2COnStateReset();
        
    }
    
    // input temp sensor
    // Write temp reg addr to read back temp sensor data
    uint8_t data_reg_pointer[1];
    data_reg_pointer[0] = MCP9804_TA_REG;
    TEMP_I2C_MasterWrite(data_reg_pointer, 1, INPUT_TEMP_SENS_ADDR, &TEMP_I2C_STATUS);
    // Read two bytes from temp reg
    TEMP_I2C_MasterRead(MCP9804_temp_results.input_temp_raw, 2, INPUT_TEMP_SENS_ADDR, &TEMP_I2C_STATUS);
    
    // pos3p3 temp sensor
    // Write temp reg addr to read back temp sensor data
    data_reg_pointer[0] = MCP9804_TA_REG;
    TEMP_I2C_MasterWrite(data_reg_pointer, 1, POS3P3_TEMP_SENS_ADDR, &TEMP_I2C_STATUS);
    // Read two bytes from temp reg
    TEMP_I2C_MasterRead(MCP9804_temp_results.pos3p3_temp_raw, 2, POS3P3_TEMP_SENS_ADDR, &TEMP_I2C_STATUS);
    
    // amb temp sensor
    // Write temp reg addr to read back temp sensor data
    data_reg_pointer[0] = MCP9804_TA_REG;
    TEMP_I2C_MasterWrite(data_reg_pointer, 1, AMB_TEMP_SENS_ADDR, &TEMP_I2C_STATUS);
    // Read two bytes from temp reg
    TEMP_I2C_MasterRead(MCP9804_temp_results.amb_temp_raw, 2, AMB_TEMP_SENS_ADDR, &TEMP_I2C_STATUS);
    
    // bckp temp sensor
    // Write temp reg addr to read back temp sensor data
    data_reg_pointer[0] = MCP9804_TA_REG;
    TEMP_I2C_MasterWrite(data_reg_pointer, 1, BCKP_TEMP_SENS_ADDR, &TEMP_I2C_STATUS);
    // Read two bytes from temp reg
    TEMP_I2C_MasterRead(MCP9804_temp_results.bckp_temp_raw, 2, BCKP_TEMP_SENS_ADDR, &TEMP_I2C_STATUS);
    
    // we're done acquiring new data
    MCP9804_start_flag = 0;
    
    telemetry_update_flag_i2c = 1;
    
}

// This function converts all raw byte value of temperature into floats for telemetry
void MCP9804BatchConvert(void) {
    
    telemetry.current.params.input_temperature = MCP9804BytesToFloat(MCP9804_temp_results.input_temp_raw);
    telemetry.current.params.pos3p3_temperature = MCP9804BytesToFloat(MCP9804_temp_results.pos3p3_temp_raw);
    telemetry.current.params.ambient_temperature = MCP9804BytesToFloat(MCP9804_temp_results.amb_temp_raw);
    telemetry.current.params.backup_temperature = MCP9804BytesToFloat(MCP9804_temp_results.bckp_temp_raw);
    
}

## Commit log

2019-05-09 Added KiCad files, started developing hardware
    [Binary_Clock_LEDs.sch, Calendar_LEDs_1.sch, Calendar_LEDs_2.sch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]
2019-05-09 Added temp sensors, other stuff
    [Binary_Clock_LEDs.sch, Calendar_LEDs.sch, Calendar_LEDs_1.sch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]
2019-06-20 Extensive LED drive restructuring
    [Analog_Conditioning.sch, Binary_Clock_LEDs.sch, Calendar_LEDs.sch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]
2019-07-17 Designed better date decoding
    [Date_Decoder.sch, Microcontroller.sch]
2019-07-20 Added software project, ported old code
    [Analog_Conditioning.sch, Binary_Clock_LEDs.sch, Calendar_LEDs.sch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]
2019-07-21 Schematic adjustments, PN assignments, footprints
    [Analog_Conditioning.sch, Binary_Clock_LEDs.sch, Calendar_LEDs.sch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]
2019-07-30 Begn laying out PCB
    [Analog_Conditioning.sch, Binary_Clock_LEDs.sch, Calendar_LEDs.sch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]
2019-07-31 Arranged a few more PCB sections
    [Analog_Conditioning.sch, Binary_Clock_LEDs.sch, Date_Decoder.sch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]
2019-08-06 More PCB part placement
    [Analog_Conditioning.sch, Binary_Clock_LEDs.sch, Calendar_LEDs.sch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]
2019-08-07 More part arranging on PCB
    [Analog_Conditioning.sch, Binary_Clock_LEDs.sch, Calendar_LEDs.sch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]
2019-08-07 even more arranging
    [Electronic_Calendar.kicad_pcb, Temperature_Sensors.sch]
2019-08-07 Finished grouping parts on PCB
    [Binary_Clock_LEDs.sch, Calendar_LEDs.sch, Electronic_Calendar.kicad_pcb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]
2019-08-08 Decided on shape and placed sections onto PCB
    [Electronic_Calendar.kicad_pcb, POS12_Input.sch, USB_UART_Bridge.sch]
2019-08-12 Began routing
    [Electronic_Calendar.kicad_pcb]
2019-08-13 More routing
    [Electronic_Calendar.kicad_pcb]
2019-08-15 Way more routing
    [Electronic_Calendar.kicad_pcb, Microcontroller.sch]
2019-08-15 Even more routing
    [Electronic_Calendar.kicad_pcb, Microcontroller.sch]
2019-08-27 Finished routing
    [Electronic_Calendar.kicad_pcb, Microcontroller.sch]
2019-09-22 Updated PDF, BOM, Gerbers
    [Electronic_Calendar-B_Cu.gbr, Electronic_Calendar-B_Mask.gbr, Electronic_Calendar-B_Paste.gbr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]
2019-09-22 Added pin macros to firmware project
2019-10-03 Got heartbeat functionality working
    [Electronic_Calendar.xlsx, configuration.h]
2019-10-06 Got ring buffer based USB UART working
2019-10-07 Got basic DMA uart working, buffer still doesn't work
    [error_handler.c, main.c]
2019-10-08 Got DMA based USB UART transmit working
2019-10-08 Renamed firmware directory, added peripheral and interrupt spreadsheets
    [Interrupt_Priority_List.xlsx, Microcontroller_Peripheral_Map.xlsx, configuration.h]
2019-10-09 Got DMA based USB UART RX working
2019-10-09 USB UART DMA refinements
2019-10-09 Added cause of reset detection
    [main.c]
2019-10-11 Got a lot of calendar LEDs working
2019-10-13 Added isolation between usb uart tx and rx
2019-10-13 Added day LED driving stuff
2019-10-18 Converted usb uart LUT to hash table based implementation
2019-10-22 Added more USB UART commands to hash table
2019-10-22 USB UART bug fixes
2019-10-24 Got ADC working
2019-10-25 Fixed strange ADC conversion issues. Had to slow down sampling speed.
    [adc.c]
2019-10-29 Added telemetry
    [configuration.h]
2019-10-30 Added telemetry tracking, min and max telemetry, fixed underscore serial text, refactored ADC code, changed config words to disable WDT and DMT at boot
    [32mz_interrupt_control.c, adc.c, main.c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]
2019-11-02 Refactored error handling to be loopable
    [adc.c, error_handler.c, main.c]
2019-11-02 Made error handler a persistent data type
    [error_handler.c, main.c]
2019-11-02 Error handler fixes, optimized ADC timing
    [adc.c, error_handler.c]
2019-11-03 Got MCP9804 I2C temp sensors working
2019-11-05 USB UART in weird state
    [configuration.h]
2019-11-05 DMT fixes
    [configuration.h]
2019-11-06 Few tweaks, trying to fix WDT timeouts
    [error_handler.c, main.c, mcp9804_temp_sensor.c]
2019-11-09 I2C in weird state
2019-11-10 Starting over with firmware
    [Interrupt_Priority_List.xlsx, Microcontroller_Peripheral_Map.xlsx, configuration.h]
2019-11-11 got old project working again, ditched new project
    [Interrupt_Priority_List.xlsx, Microcontroller_Peripheral_Map.xlsx, configuration.h]
2019-11-11 Changed REFCLK PMD setting to enabled per device errata
    [power_saving.c]
2019-11-11 made a few more variable volatile
    [Interrupt_Priority_List.xlsx]
2019-11-12 fixes to ADC code to resolve random CPU exceptions
    [adc.c, main.c, mcp9804_temp_sensor.c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]
2019-11-12 fixed ADC exception issues
    [adc.c]
2019-11-12 i2c tweaks
2019-11-13 Seems like I2C temp sensors are now working
2019-11-13 Switched to I2C non-blocking implementation, it works!
2019-11-13 Added power cap touch ISRs
2019-11-16 optimized USB UART RX string check further
2019-11-17 Few tweaks on error handler and I2C
    [temp_i2c.c]
2019-11-17 added clock switch
